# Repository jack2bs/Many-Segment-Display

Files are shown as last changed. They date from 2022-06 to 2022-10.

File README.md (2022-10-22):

# <center>Many Segment Display</center>
A four-digit display, made from 68 seven segment displays! By Jack Toubes. Inspired by [This Hackaday Project](https://hackaday.io/project/169632-7-segment-display-array-clock).

## Overview and conclusions
When I saw the above linked Hackaday project a while back, I thought it was the funniest thing I'd ever seen. But I didn't have the skills or money required to build something like it. Last year, however, when I got to my dorm room and realized that I hadn't brought a clock with me to school, I remembered that Hackaday project and I thought I'd give it a shot. I saw some places where I could improve the original, especially in the cost of the project. In the end the project took me a couple of months of on and off work (dictated by how busy I was with school). This project, like many of my other similar projects, offered me the opportunity to hone my electronic design skills, my ability to learn from datasheets, my ability to program in c and c++, and my ability to work with microcontrollers.

## Improvements from original project

For starters, I didn't copy a single line of code nor a component nor part of the schematic/board design from the original project. I was inspired by the idea, but not by the implementation.

In the original project on *Hackaday*, the LEDs are driven using dedicated LED driver ICs named MAX7219's, each of which could drive 8 seven segment displays. While this option certainly simplifies the board design and project in general, I decided to use 8-bit latches and some address decoders instead. 8 of these 8-bit latches are significantly cheaper than a single LED controller used in the *Hackaday* project, yet can control the same number of LEDs. This solution does require a significant number more pins/data lines, and a much more complicated circuit board, however I consider this worthwhile, considering that my LED driving solution costs $20-$25, whereas 9 of the dedicated LED drivers would cost between $90-$110 dollars. Using shift registers but not dedicated LED drivers would lead to a cost somewhere in between the two options, and could serve as a good compromise, considering that the board design would still be complex, but the number of data lines would be significantly reduced. One issue with the shift registers (and as a consequence also of the LED driver ICs), is that to change a single LED's state, you must update all of them. With my solution, you can change any LED at any time without affecting the others. The actual benefits to this are somewhat limited but could prove consequential in certain applications. One disadvantage with using latches is that they aren't designed to provide high amounts of current, and so (slightly more expensive) low current LEDs had to be chosen. This did however lead to a much less power hungry design than in the *Hackaday* project so perhaps this could also be considered a positive depending on your perspective

The original project used an Arduino. I used an STMG441 MCU on a custom controller board, because I have issues with Arduino as a platform (in my opinion, it's good for learning, but bad for everything else. Like how is acceptable for a pin change to take 80 cycles instead of 2 using memory-mapped io?!?! https://timodenk.com/blog/port-manipulation-and-arduino-digitalwrite-performance/).

I decreased the size of the clock significantly to lower costs, decrease power consumption, and because a smaller version fits better in my dorm. Even had I not done this, the price would have been somewhere around 1/3 - 1/2 that of the original, but by decreasing the size it was decreased even more.

The rest of my decisions were uninfluenced by the project (which is to say that as far as I'm aware my implementation is different from the original in every way except that both receive power over USB).

## Parts (prices as of part purchasing)

| Part | Part Number | Manufacturer | Price (Digikey) |  link | Price (Mouser) | link | Quantity |
|--|--|--|--|--|--|--|--|
|Display Parts
| 7-Seg Display | TDSR1360-IK | Vishay Semi | $1.43 for 10 | [Digikey](https://www.digikey.com/en/products/detail/vishay-semiconductor-opto-division/TDSR1360-IK/4074625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)| $1.29 for 10 | [Mouser](https://www.mouser.com/ProductDetail/Vishay-Semiconductors/TDSR1360-IK?qs=5csRq1wdUj5b9hoSL0MeOw%3D%3D) | 68+
| 8-bit Latch | 74LCX573FTAJ | Toshiba Semi | $0.207 for 100 | [Digikey](https://www.digikey.com/en/products/detail/toshiba-semiconductor-and-storage/74LCX573FT-AJ/7394038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)| $0.209 for 100 | [Mouser](https://www.mouser.com/ProductDetail/Toshiba/74LCX573FTAJ?qs=HXFqYaX1Q2ziMe06wbpr9A%3D%3D) | 68+
| 4:16 Decoder | 74HC4514D,653 | Nexperia Semi | $1.58 for 1 | [Digikey](https://www.digikey.com/en/products/detail/nexperia-usa-inc/74HC4514D-653/1230450)| $1.58 for 1 | [Mouser](https://www.mouser.com/ProductDetail/Nexperia/74HC4514D653?qs=P62ublwmbi%252Bpl7vJN0RpAQ%3D%3D) | 5+
| 3:8 (inv) Decoder | 74HC138D | Toshiba Semi | $0.41 for 1 | [Digikey](https://www.digikey.com/en/products/detail/toshiba-semiconductor-and-storage/74HC138D/5879983)| $0.41 for 1 | [Mouser](https://www.mouser.com/ProductDetail/Toshiba/74HC138DBJ?qs=sGAEpiMZZMsyYdr3R27aVzR9lUdn91FlizOQe6UfcVY%3D) | 1+
| Micro USB Conn | USB3076-30-A | GCT | $0.73 for 1 | [Digikey](https://www.digikey.com/en/products/detail/gct/USB3076-30-A/9859635)| $0.70 for 1 | [Mouser](https://www.mouser.com/ProductDetail/GCT/USB3076-30-A?qs=sGAEpiMZZMv0NwlthflBi%2FFq8vjDHSW5SIbIh%2F36DKc%3D) | 1+
| 1V8 LVR | AP2112K1.8TRG1 | Diodes Inc. | $0.37 for 1 | [Digikey](https://www.digikey.com/en/products/detail/diodes-incorporated/AP2112K-1-8TRG1/4470745)| $0.37 for 1 | [Mouser](https://www.mouser.com/ProductDetail/Diodes-Incorporated/AP2112K-18TRG1?qs=x6A8l6qLYDBx1xhw8AX2cw%3D%3D) | 4+
| 3V3 LVR | AP2139AK3.3TRG1 | Diodes Inc. | $0.42 for 1 | [Digikey](https://www.digikey.com/en/products/detail/diodes-incorporated/AP2139AK-3-3TRG1/4470806)| $0.42 for 1 | [Mouser](https://www.mouser.com/ProductDetail/Diodes-Incorporated/AP2139AK-33TRG1?qs=x6A8l6qLYDAPOgDKaB%252BUdg%3D%3D) | 1+
| 1uF Cap | C0805C105Z4VACTU | KEMET | $0.077 for 10 | [Digikey](https://www.digikey.com/en/products/detail/kemet/C0805C105Z4VAC7800/2211782)| $0.046 for 10 | [Mouser](https://www.mouser.com/ProductDetail/KEMET/C0805C105Z4VACTU?qs=XSafd0xJmRINotKjOdb5hw%3D%3D) | 10+
| |
| Controller Parts |
|Microcontroller | STM32G441 | STM | Not in stock | [Digikey](https://www.digikey.com/en/products/detail/stmicroelectronics/STM32G441CBT6/10326710) | Not in stock | [Mouser](https://www.mouser.com/ProductDetail/STMicroelectronics/STM32G441CBY6TR?qs=BJlw7L4Cy798X5l%252BURHnLA%3D%3D) | 1+
|32Khz Crystal | ECS-.327-12.5-34B-C-TR | ECS inc. | $0.80 for 1 | [Digikey](https://www.digikey.com/en/products/detail/ecs-inc/ECS-327-12-5-34B-C-TR/3927328) | $0.80 for 1 | [Mouser](https://www.mouser.com/ProductDetail/ECS/ECS-.327-12.5-34B-C-TR?qs=wo4x%252BUeoG8VWo%2FRy18ZjoQ%3D%3D) | 1+
|Assorted Components | N/A | N/A | ~$12 | | ~$12 | |

## Preliminary Considerations

Early on in the project, I wanted to test the electronics to confirm that my part selections would be satisfactory for the project. Specifically, I wanted to make sure the latches I would using could take 1.8v in VCC (and thus output 1.8v), but use 3.3v on their inputs. To do this, I designed a small breakout board for the latch, so that I could test it on a bread board, and ordered it from OSH Park for a couple of bucks. The KiCad project (including schematic, board layout, and Gerber files) is inside of the PCB_and_schematic/SubProjects/LatchTest directory.

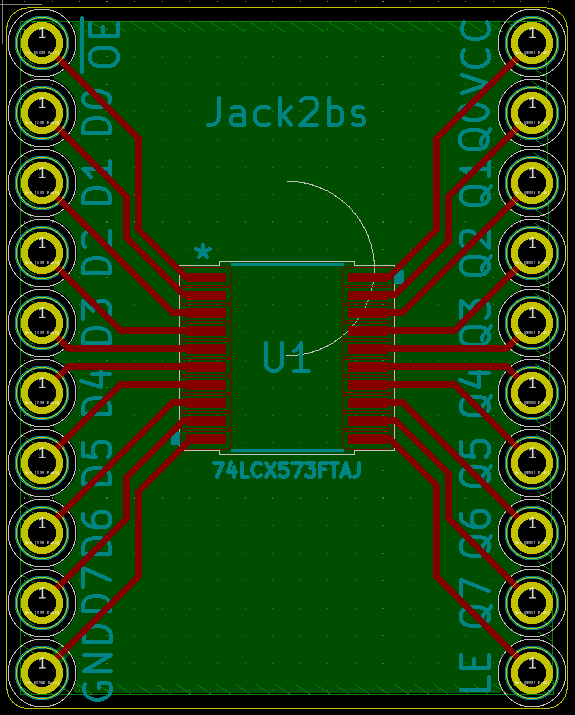
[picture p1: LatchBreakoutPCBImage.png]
Latch Breakout PCB


I also wanted to construct a development board for the STM32G441, which I decided I would use for controlling the display since I had some of them in my supplies and all microcontrollers were and still are out of stock. I designed and ordered a board from Osh Park (still small enough that the shipping for the two boards was more than the cost of the boards). I used the development board for testing RTC functionality and making sure that I could interconnect with the latches using basic GPIO. I have continued to use the development board for other prototyping and educational uses. The KiCad project files are inside of the same subprojects folder, but in the STM32G441DevBoard subdirectory.

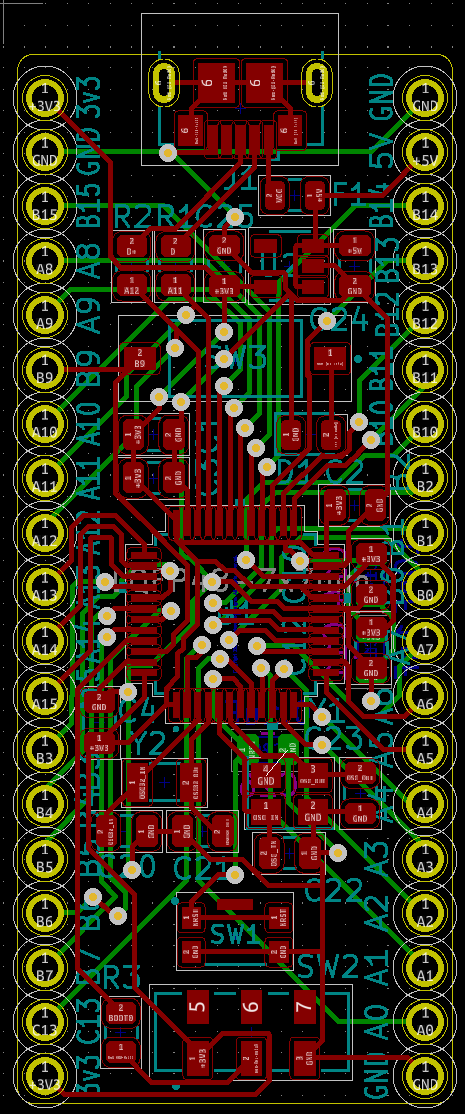
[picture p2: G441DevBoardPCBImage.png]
G441 Development board


## Laying out the board
After confirming that the electronics would work in the way I intended them to, I began laying out the board. I originally planned to build the controller directly into the board, but decided against this once I realized how many points of failure I was putting on one circuit board. Had I been producing this board with high tech, industrial grade soldering ovens I wouldn't have been concerned, but I was hand soldering the components, and with 68 20-TSSOP latches, and tons of other components (mostly surface mount), there was a lot that could go wrong. This meant laying out two separate boards.

First was the display itself. This took by far the greatest amount of time of any circuit board I've ever designed, and for good reason. With the final board having over 7500 Track segments spanning 660 nets, this boards complexity was greater than anything I'd ever attempted, and I was going to do it on a two layer board, which was covered both front and back with components. I started by drawing tracks somewhat randomly as I thought made sense, but I quickly realized this technique would not be effective. I deleted my progress and started again. This time, I took a more systematic approach. I created what to me seemed like "highways" of tracks which would carry the signals which needed to span the entire width of the board. This set up a good basis for using the top layer for signal transmission along the x axis, and the bottom layer for transmission along the y axis. After this, I moved again to fill in the connections that were not along the so called highways, but found myself running into trouble with the lack of space due to the components. The solution was to add complexity to the connections between the latches and the seven segment displays. Originally I had wanted to connect Q0 on the latch to A on the 7-segment display, Q1 to B, etc. I realized that for layout purposes this was not ideal, and so I redid all of the latch connections on the schematic, and again turned to the circuit board. Add another week or so of time, another 3 or 4 (hundred) problems solved, and I had a finished the circuit board.

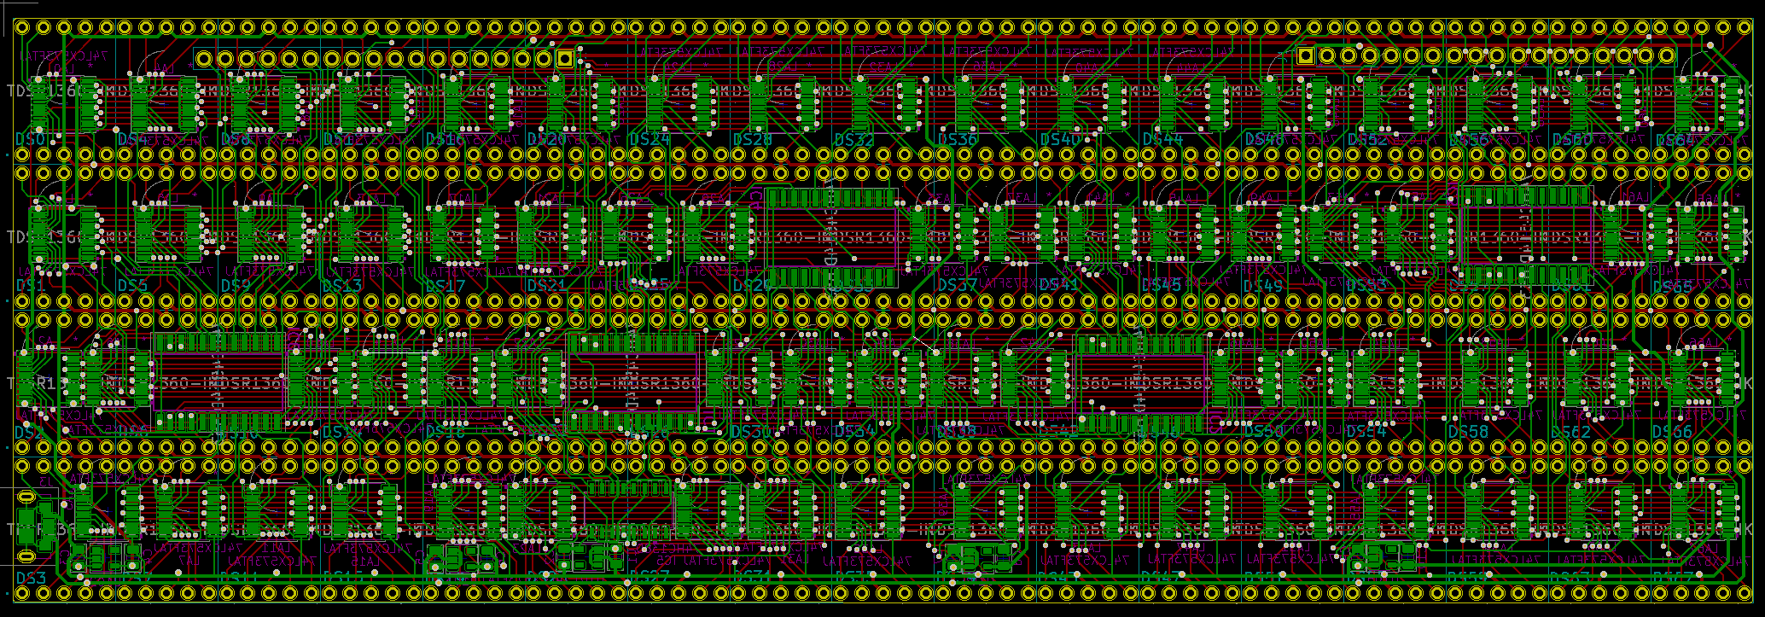
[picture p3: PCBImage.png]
Many Segment Display PCB


Laying out the controller was much easier, as I was able to base it heavily off of the development board I had designed earlier. Photos of the two circuit boards are located in this repository, and the KiCad project files are all in here as well (the controller is in the subprojects folder). The controller slots into the main board using header pins.

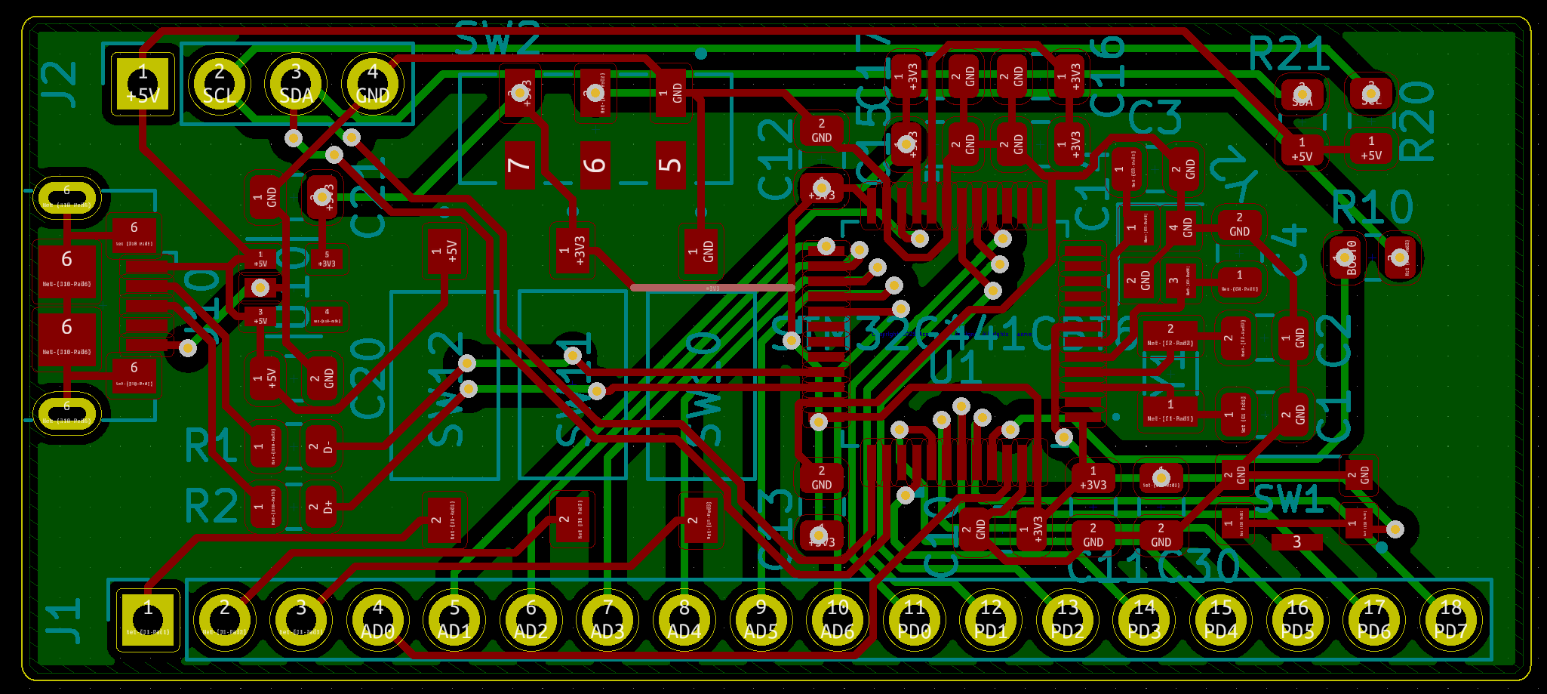
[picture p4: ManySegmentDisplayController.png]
Many Segment Display Controller


Once the boards came I spent a few days in one of the Makerspaces here at Princeton and I soldered on all of the components.

## Writing the software

It was relatively uncomplicated to write a short API for controlling the different cells of the display. The code for this is (admittedly) very messy and thrown together, but it wasn't the purpose of this project and it is functional. It isn't my best work by any stretch, and if I find the time between newer projects and my school work, I may update it.

Writing code to initialize and control the RTC (over USB using a CDC library) was similarly uncomplicated, but was made more difficult by the imperfections of my soldering job. Specifically, the quartz crystal wouldn't always begin oscillating. It took a significant amount of time, but eventually I realized that by cleaning up the solder job and removing the left over flux residue, I was able to coerce the crystal into oscillating.

I spent a few days after this calibrating the RTC until it was accurate to a fraction of a part per million, and then I put the final clock up in my dorm. 

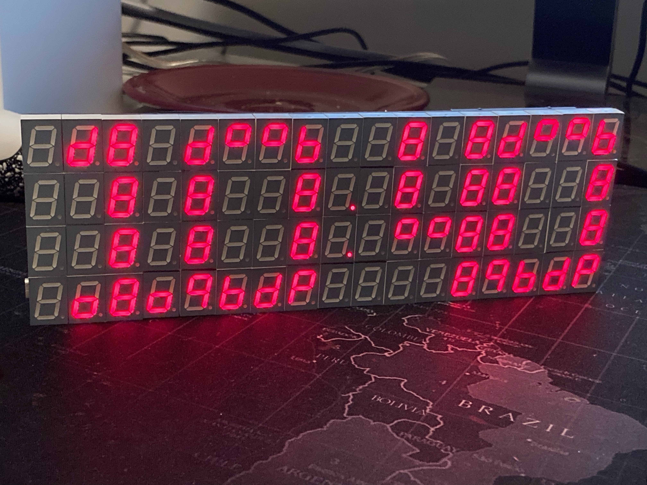
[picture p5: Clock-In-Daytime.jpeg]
Clock up and running


> Written with [StackEdit](https://stackedit.io/).

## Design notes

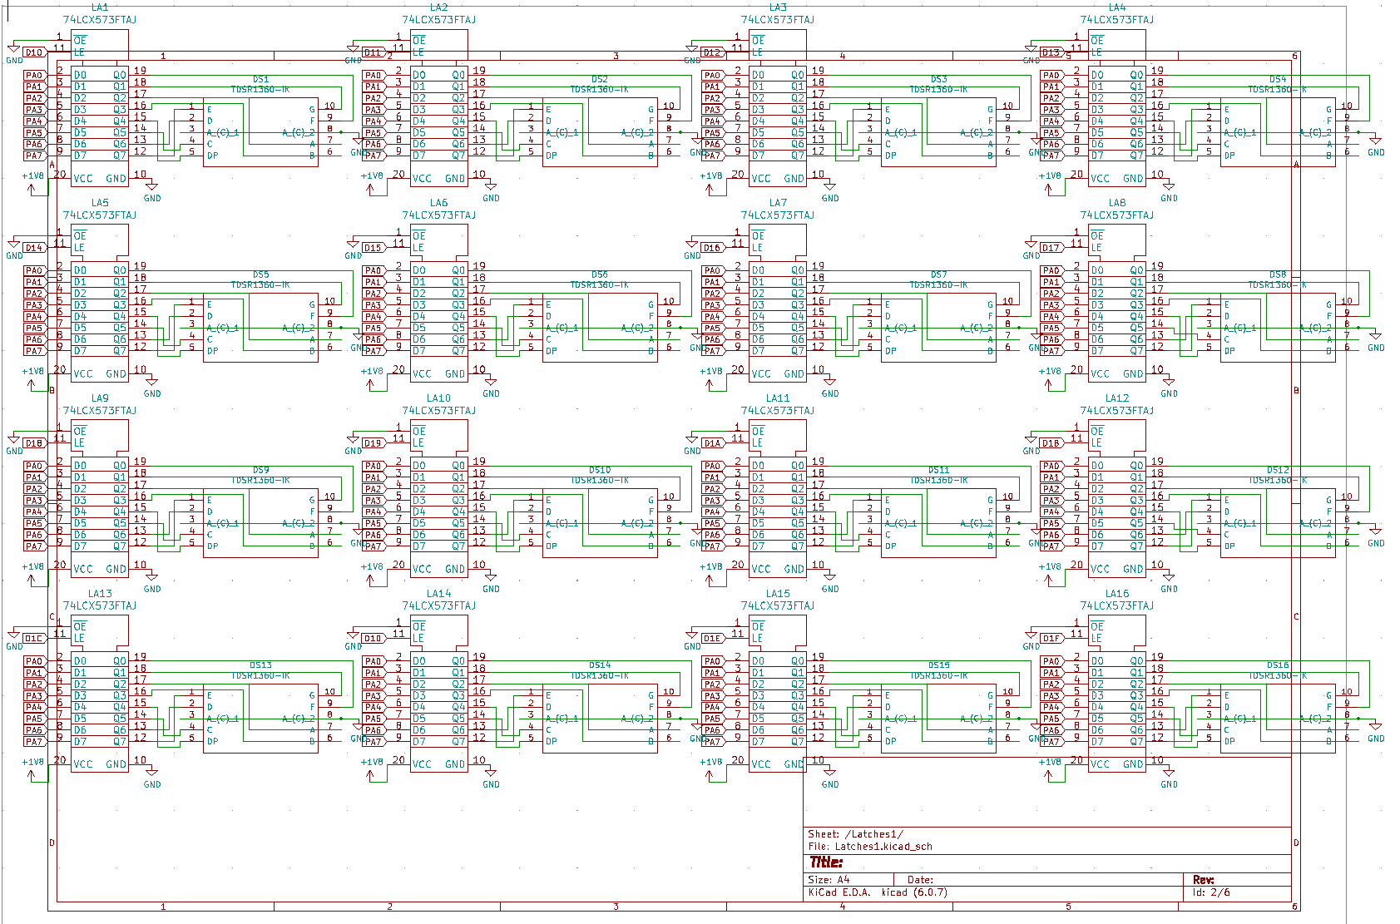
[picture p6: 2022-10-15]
SchematicLatchPage1.png

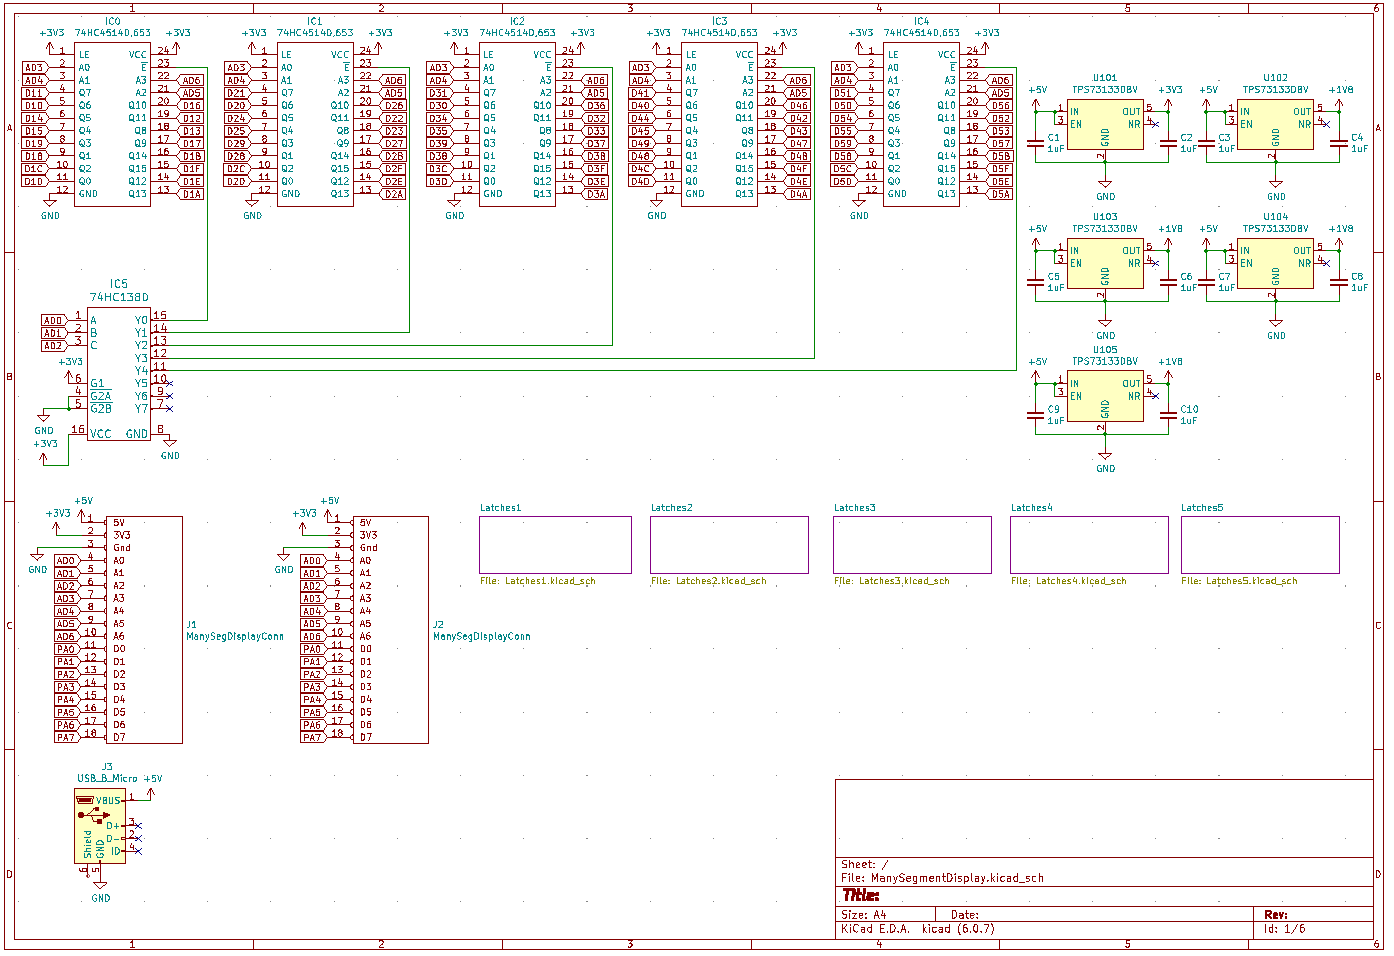
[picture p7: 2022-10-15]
MainSchematicImage.png

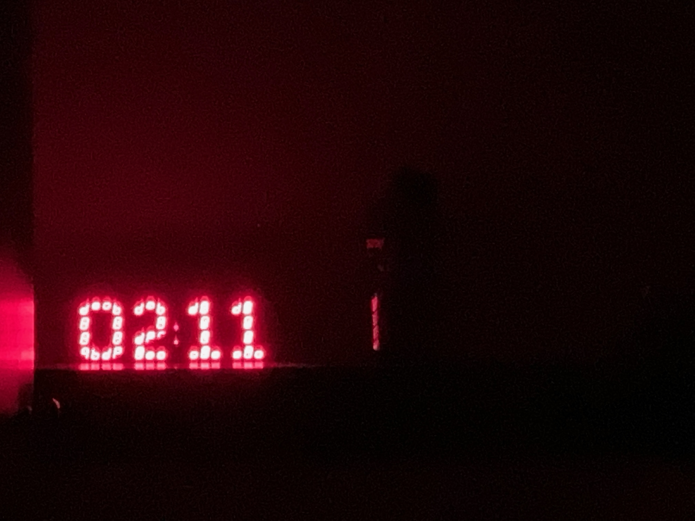
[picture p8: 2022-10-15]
Clock-In-Nighttime.jpeg

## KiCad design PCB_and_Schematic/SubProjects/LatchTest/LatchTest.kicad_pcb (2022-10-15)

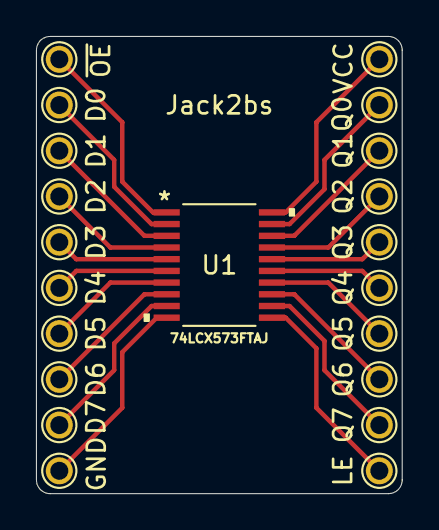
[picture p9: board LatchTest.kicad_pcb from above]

Board: 2 copper layers, 20.3 x 25.4 mm, 20 parts (0 on the bottom side), 19 nets.

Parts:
D0, D1, D2, D3, D4, D5, D6, D7: TestPoint; TestPoint_THTPad_D1.5mm_Drill0.7mm
GND: TestPoint; TestPoint_THTPad_D1.5mm_Drill0.7mm
LE: TestPoint; TestPoint_THTPad_D1.5mm_Drill0.7mm
Q0, Q1, Q2, Q3, Q4, Q5, Q6, Q7: TestPoint; TestPoint_THTPad_D1.5mm_Drill0.7mm
U1: 74LCX573FTAJ
VCC: TestPoint; TestPoint_THTPad_D1.5mm_Drill0.7mm

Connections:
unnamed: D0.1, U1.2
unnamed: D1.1, U1.3
unnamed: D2.1, U1.4
unnamed: D3.1, U1.5
unnamed: D4.1, U1.6
unnamed: D5.1, U1.7
unnamed: D6.1, U1.8
unnamed: D7.1, U1.9
unnamed: Q0.1, U1.19
unnamed: Q1.1, U1.18
unnamed: Q2.1, U1.17
unnamed: Q3.1, U1.16
unnamed: Q4.1, U1.15
unnamed: Q5.1, U1.14
unnamed: Q6.1, U1.13
unnamed: Q7.1, U1.12
unnamed: LE.1, U1.11
unnamed: GND.1, U1.10
unnamed: U1.20, VCC.1

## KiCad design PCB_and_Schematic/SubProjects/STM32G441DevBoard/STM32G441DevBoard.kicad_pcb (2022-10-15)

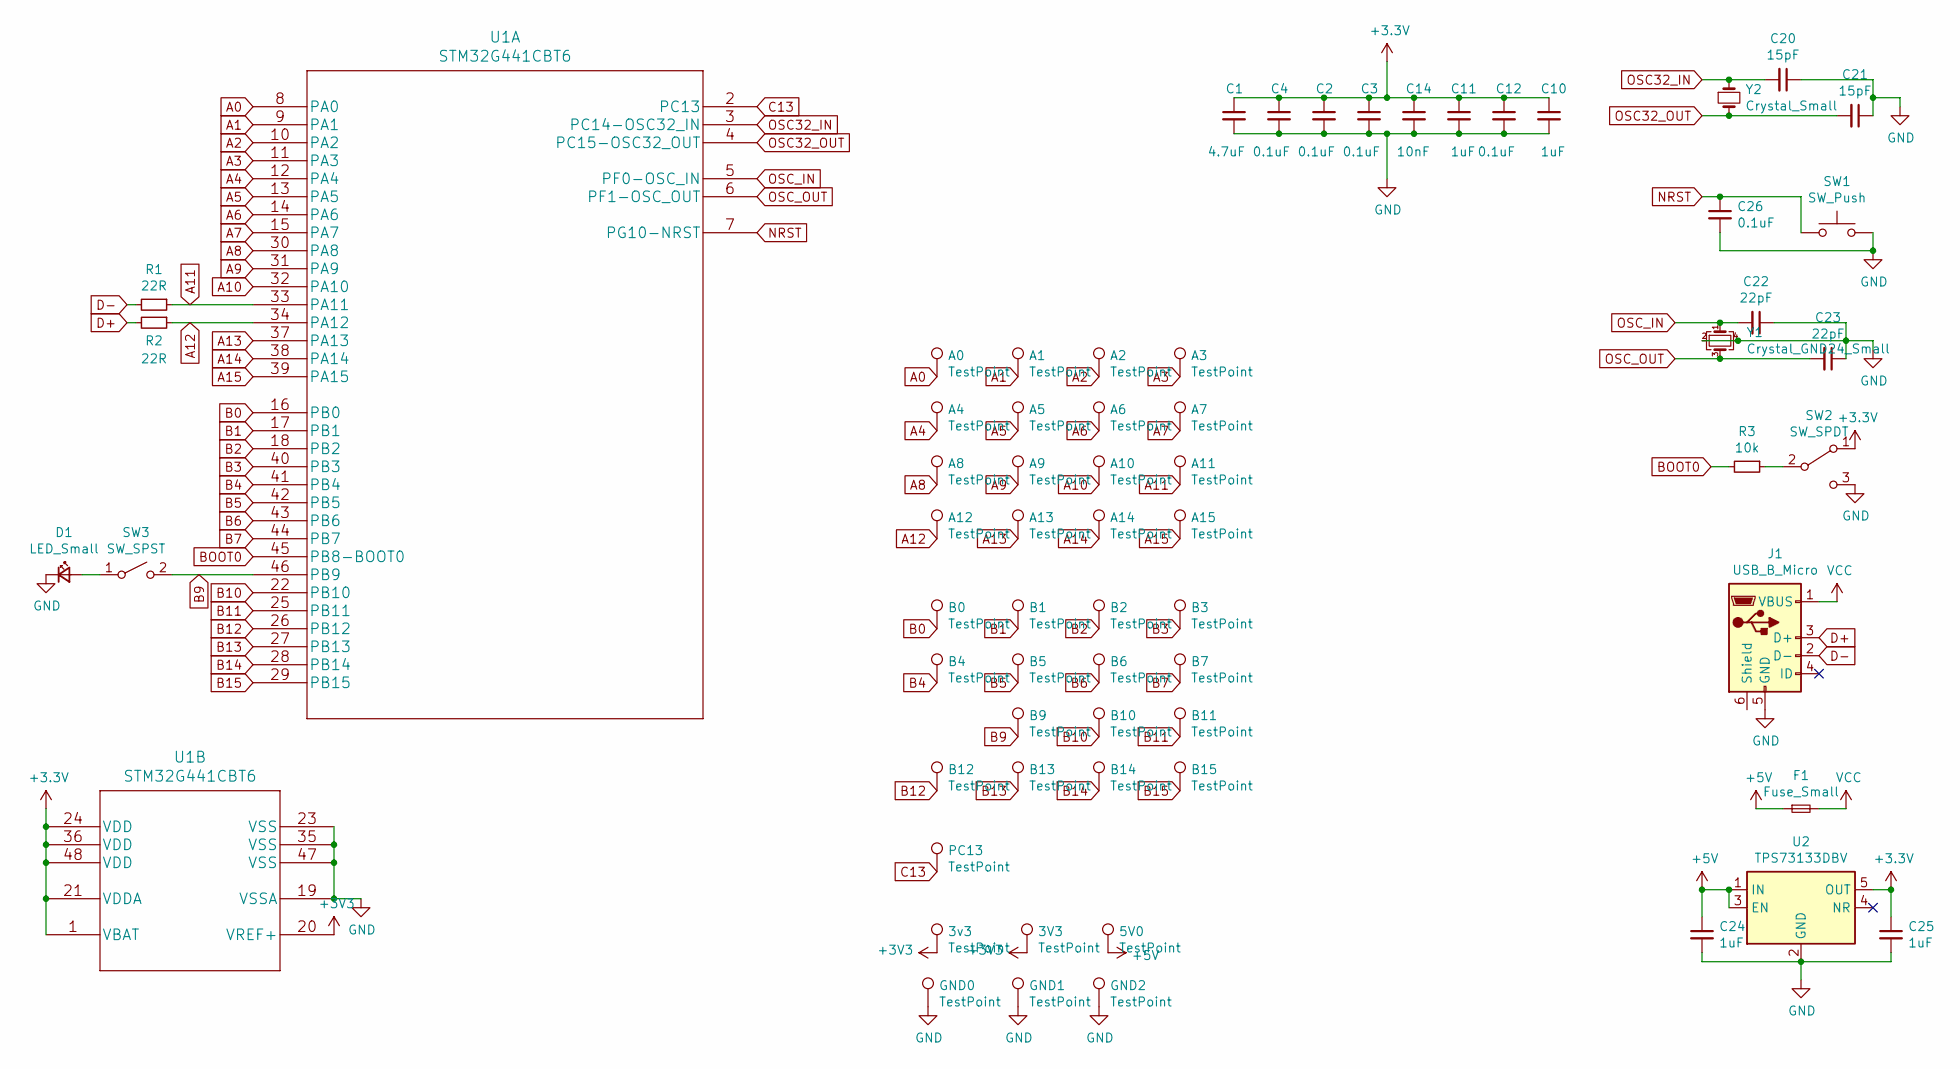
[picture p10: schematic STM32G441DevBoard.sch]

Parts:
3V3, 3v3, 5V0: TestPoint; TestPoint_THTPad_D1.775mm_Drill1.2mm
A0, A1, A2, A3, A4, A5, A6, A7, A8, A9, A10, A11, A12, A13, A14, A15: TestPoint; TestPoint_THTPad_D1.775mm_Drill1.2mm
B0, B1, B2, B3, B4, B5, B6, B7, B9, B10, B11, B12, B13, B14, B15: TestPoint; TestPoint_THTPad_D1.775mm_Drill1.2mm
C1: 4.7uF; C_0805_2012Metric
C2, C3, C4, C12, C26: 0.1uF; C_0805_2012Metric
C10, C11, C24, C25: 1uF; C_0805_2012Metric
C14: 10nF; C_0805_2012Metric
C20, C21: 15pF; C_0805_2012Metric
C22, C23: 22pF; C_0805_2012Metric
D1: LED_Small; LED_0805_2012Metric
F1: Fuse_Small; Fuse_0805_2012Metric
GND0, GND1, GND2: TestPoint; TestPoint_THTPad_D1.775mm_Drill1.2mm
J1: USB_B_Micro; USB_Micro-B_GCT_USB3076-30-A
PC13: TestPoint; TestPoint_THTPad_D1.775mm_Drill1.2mm
R1, R2: 22R; R_0805_2012Metric
R3: 10k; R_0805_2012Metric
SW1: SW_Push; SW_Push_KMR421GULCLFS
SW2: SW_SPDT; SW_SPDT_JS202011JCQN
SW3: SW_SPST; SW_DIP_SPSTx01_DS04-254-2-01BK-SMT
U1: STM32G441CBT6
U2: TPS73133DBV; SOT-23-5
Y1: Crystal_GND24_Small; Crystal_SMD_3225-4Pin_3.2x2.5mm
Y2: Crystal_Small; Crystal_SMD_3215-2Pin_3.2x1.5mm

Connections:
+5V: 5V0.1, C24.1, F1.1, U2.1 (IN), U2.3 (EN); also elsewhere on the board
A0: A0.1, U1.8 (PA0)
A1: A1.1, U1.9 (PA1)
A2: A2.1, U1.10 (PA2)
A3: A3.1, U1.11 (PA3)
A4: A4.1, U1.12 (PA4)
A5: A5.1, U1.13 (PA5)
A6: A6.1, U1.14 (PA6)
A7: A7.1, U1.15 (PA7)
A8: A8.1, U1.30 (PA8)
A9: A9.1, U1.31 (PA9)
A10: A10.1, U1.32 (PA10)
A11: A11.1, R1.1, U1.33 (PA11)
A12: A12.1, R2.1, U1.34 (PA12)
A13: A13.1, U1.37 (PA13)
A14: A14.1, U1.38 (PA14)
A15: A15.1, U1.39 (PA15)
B0: B0.1, U1.16 (PB0)
B1: B1.1, U1.17 (PB1)
B2: B2.1, U1.18 (PB2)
B3: B3.1, U1.40 (PB3)
B4: B4.1, U1.41 (PB4)
B5: B5.1, U1.42 (PB5)
B6: B6.1, U1.43 (PB6)
B7: B7.1, U1.44 (PB7)
B9: B9.1, SW3.2 (B), U1.46 (PB9)
B10: B10.1, U1.22 (PB10)
B11: B11.1, U1.25 (PB11)
B12: B12.1, U1.26 (PB12)
B13: B13.1, U1.27 (PB13)
B14: B14.1, U1.28 (PB14)
B15: B15.1, U1.29 (PB15)
BOOT0: R3.2, U1.45 (PB8-BOOT0)
C13: PC13.1, U1.2 (PC13); also elsewhere on the board
D+: J1.3 (D+), R2.2
D-: J1.2 (D-), R1.2
GND: C1.2, C2.2, C3.2, C4.2, C10.2, C11.2, C12.2, C14.2, C20.1, C21.1, C22.1, C23.1, C24.2, C25.2, C26.2, D1.1 (K), GND0.1, GND1.1, GND2.1, J1.5 (GND), SW1.2, SW2.3 (C), U1.19 (VSSA), U1.23 (VSS), U1.35 (VSS), U1.47 (VSS), U2.2 (GND), Y1.2, Y1.4; also elsewhere on the board
NRST: C26.1, SW1.1, U1.7 (PG10-NRST)
unnamed: D1.2 (A), SW3.1 (A)
unnamed: R3.1, SW2.2 (B)
OSC32_IN: C20.2, U1.3 (PC14-OSC32_IN), Y2.1
OSC32_OUT: C21.2, U1.4 (PC15-OSC32_OUT), Y2.2
OSC_IN: C22.2, U1.5 (PF0-OSC_IN), Y1.1
OSC_OUT: C23.2, U1.6 (PF1-OSC_OUT), Y1.3
VCC: F1.2, J1.1 (VBUS)

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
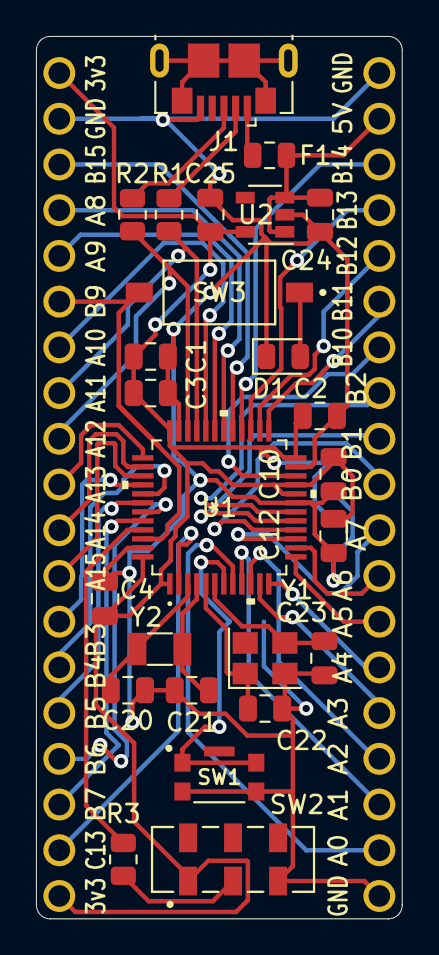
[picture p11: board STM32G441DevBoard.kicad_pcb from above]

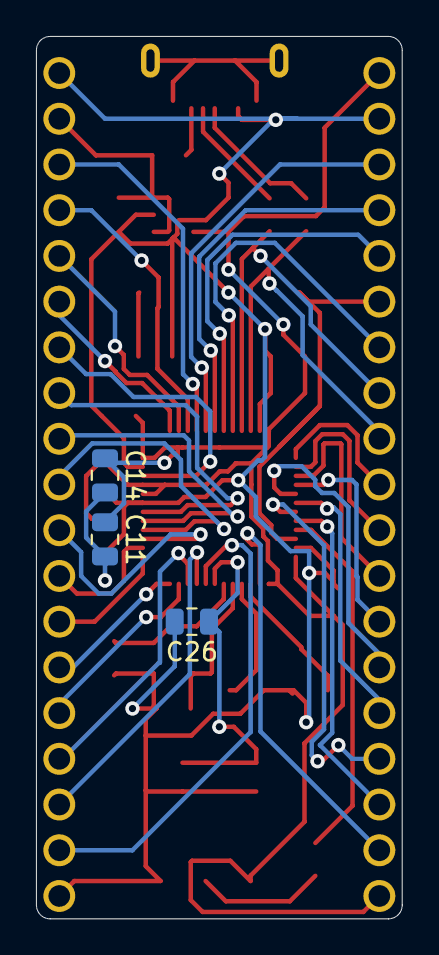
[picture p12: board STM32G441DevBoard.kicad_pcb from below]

Board: 2 copper layers, 20.3 x 49.0 mm, 66 parts (3 on the bottom side), 46 nets.

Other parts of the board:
3v3#2, 5V: TestPoint; TestPoint_THTPad_D1.775mm_Drill1.2mm
C13: TestPoint; TestPoint_THTPad_D1.775mm_Drill1.2mm
GND: TestPoint; TestPoint_THTPad_D1.775mm_Drill1.2mm
GND#2, GND#3: TestPoint; TestPoint_THTPad_D1.775mm_Drill1.2mm

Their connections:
+5V: 5V.1; also elsewhere on the board
C13: C13.1; also elsewhere on the board
GND: GND.1, GND#2.1, GND#3.1; also elsewhere on the board

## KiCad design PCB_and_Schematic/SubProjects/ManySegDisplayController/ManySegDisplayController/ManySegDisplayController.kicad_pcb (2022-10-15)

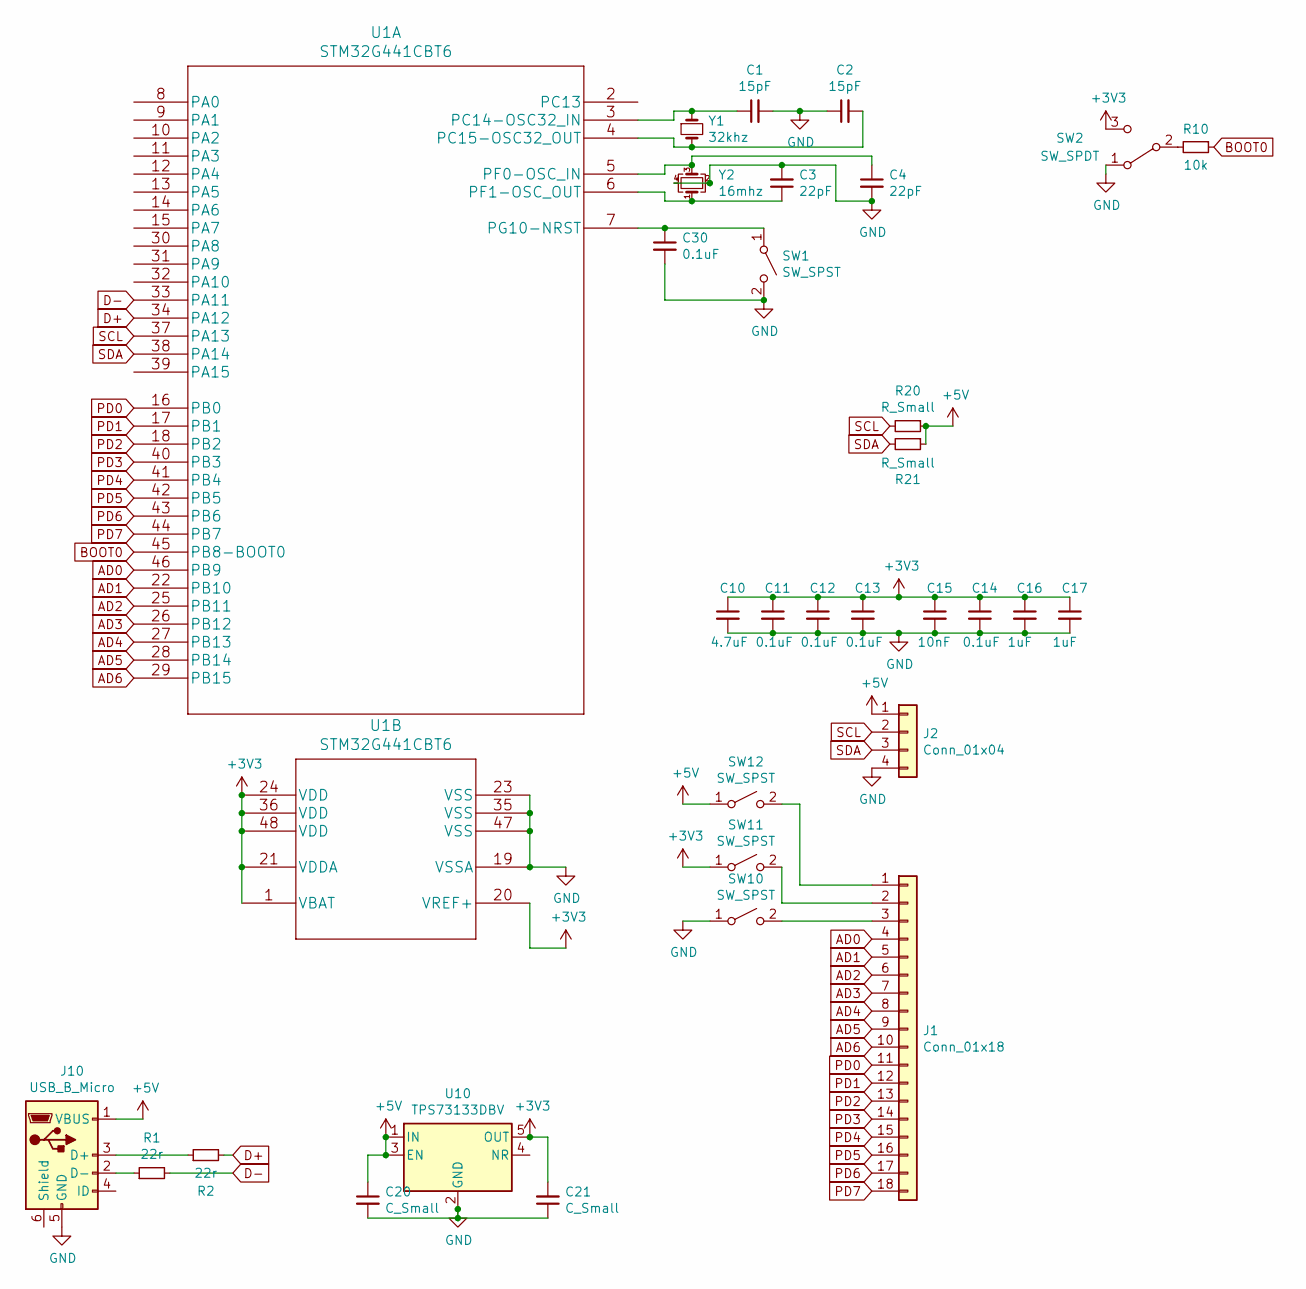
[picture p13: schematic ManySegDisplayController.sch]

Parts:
C1, C2: 15pF; C_0805_2012Metric
C3, C4: 22pF; C_0805_2012Metric
C10: 4.7uF; C_0805_2012Metric
C11, C12, C13, C14, C30: 0.1uF; C_0805_2012Metric
C15: 10nF; C_0805_2012Metric
C16, C17: 1uF; C_0805_2012Metric
C20, C21: C_Small; C_0805_2012Metric
J1: Conn_01x18; PinSocket_1x18_P2.54mm_Vertical
J2: Conn_01x04; PinSocket_1x04_P2.54mm_Vertical
J10: USB_B_Micro; USB_Micro-B_GCT_USB3076-30-A
R1, R2: 22r; R_0805_2012Metric
R10: 10k; R_0805_2012Metric
R20, R21: R_Small; R_0805_2012Metric
SW1: SW_SPST; SW_Push_KMR421GULCLFS
SW2: SW_SPDT; SW_SPDT_JS202011JCQN
SW10, SW11, SW12: SW_SPST; SW_DIP_SPSTx01_DS04-254-2-01BK-SMT
U1: STM32G441CBT6
U10: TPS73133DBV; SOT-23-5
Y1: 32khz; Crystal_SMD_3215-2Pin_3.2x1.5mm
Y2: 16mhz; Crystal_SMD_2520-4Pin_2.5x2.0mm

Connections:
+3V3: C10.1, C11.1, C12.1, C13.1, C14.1, C15.1, C16.1, C17.1, C21.2, SW2.3 (C), SW11.1 (A), U1.1 (VBAT), U1.20 (VREF+), U1.21 (VDDA), U1.24 (VDD), U1.36 (VDD), U1.48 (VDD), U10.5 (OUT)
+5V: C20.1, J2.1, J10.1 (VBUS), R20.1, R21.1, SW12.1 (A), U10.1 (IN), U10.3 (EN)
AD0: J1.4, U1.46 (PB9)
AD1: J1.5, U1.22 (PB10)
AD2: J1.6, U1.25 (PB11)
AD3: J1.7, U1.26 (PB12)
AD4: J1.8, U1.27 (PB13)
AD5: J1.9, U1.28 (PB14)
AD6: J1.10, U1.29 (PB15)
BOOT0: R10.1, U1.45 (PB8-BOOT0)
D+: R2.2, U1.34 (PA12)
D-: R1.2, U1.33 (PA11)
GND: C1.2, C2.1, C3.2, C4.2, C10.2, C11.2, C12.2, C13.2, C14.2, C15.2, C16.2, C17.2, C20.2, C21.1, C30.2, J2.4, J10.5 (GND), SW1.2 (B), SW2.1 (A), SW10.1 (A), U1.19 (VSSA), U1.23 (VSS), U1.35 (VSS), U1.47 (VSS), U10.2 (GND), Y2.2, Y2.4
unnamed: C1.1, U1.3 (PC14-OSC32_IN), Y1.1
unnamed: C2.2, U1.4 (PC15-OSC32_OUT), Y1.2
unnamed: C3.1, U1.6 (PF1-OSC_OUT), Y2.1
unnamed: C4.1, U1.5 (PF0-OSC_IN), Y2.3
unnamed: C30.1, SW1.1 (A), U1.7 (PG10-NRST)
unnamed: J1.1, SW12.2 (B)
unnamed: J1.2, SW11.2 (B)
unnamed: J1.3, SW10.2 (B)
unnamed: J10.2 (D-), R1.1
unnamed: J10.3 (D+), R2.1
unnamed: R10.2, SW2.2 (B)
PD0: J1.11, U1.16 (PB0)
PD1: J1.12, U1.17 (PB1)
PD2: J1.13, U1.18 (PB2)
PD3: J1.14, U1.40 (PB3)
PD4: J1.15, U1.41 (PB4)
PD5: J1.16, U1.42 (PB5)
PD6: J1.17, U1.43 (PB6)
PD7: J1.18, U1.44 (PB7)
SCL: J2.2, R20.2, U1.37 (PA13)
SDA: J2.3, R21.2, U1.38 (PA14)

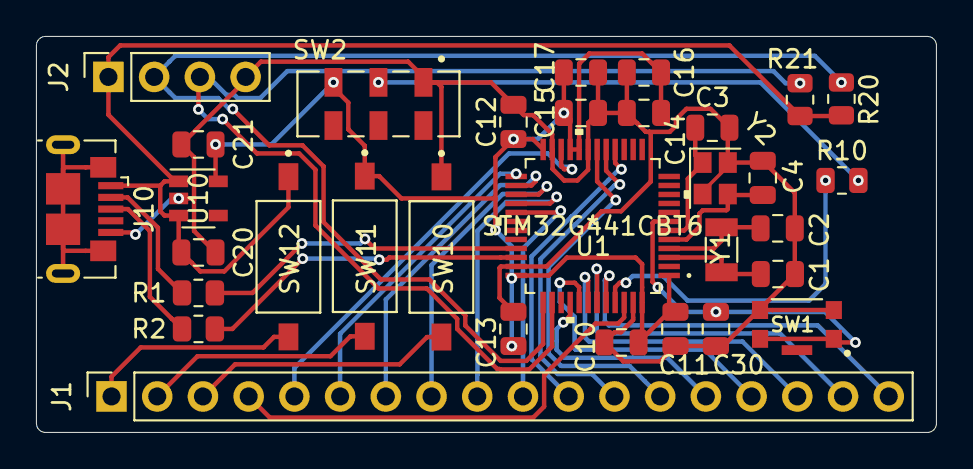
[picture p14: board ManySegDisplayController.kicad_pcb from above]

Board: 2 copper layers, 50.0 x 22.0 mm, 32 parts (0 on the bottom side), 34 nets.

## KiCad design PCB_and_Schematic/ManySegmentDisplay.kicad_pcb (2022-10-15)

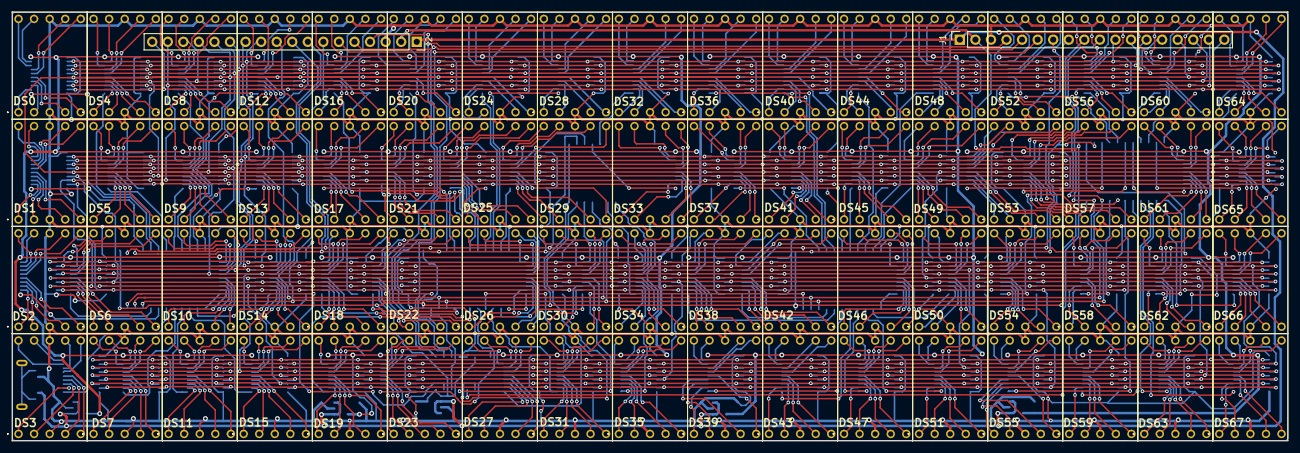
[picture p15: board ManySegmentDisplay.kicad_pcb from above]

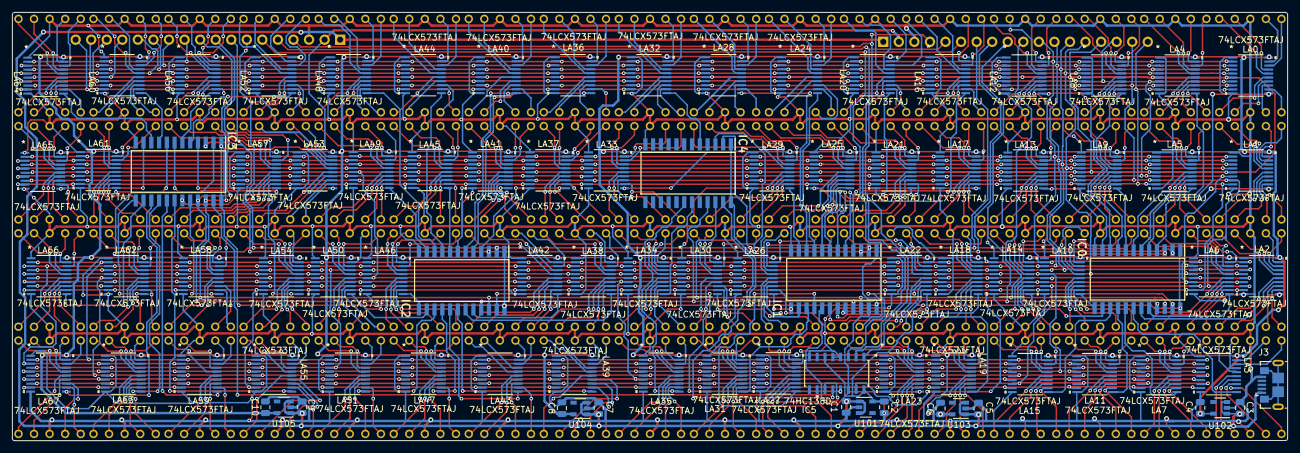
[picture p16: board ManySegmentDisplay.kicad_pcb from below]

Board: 2 copper layers, 208.1 x 69.9 mm, 160 parts (90 on the bottom side), 636 nets.

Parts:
C1, C2, C3, C4, C5, C6, C7, C8, C9, C10: 1uF; C_0805_2012Metric
DS0, DS1, DS2, DS3, DS4, DS5, DS6, DS7, DS8, DS9, DS10, DS11, DS12, DS13, DS14, DS15, DS16, DS17, DS18, DS19, DS20, DS21, DS22, DS23, DS24, DS25, DS26, DS27, DS28, DS29, DS30, DS31, DS32, DS33, DS34, DS35, DS36, DS37, DS38, DS39, DS40, DS41, DS42, DS43, DS44, DS45, DS46, DS47, DS48, DS49, DS50, DS51, DS52, DS53, DS54, DS55, DS56, DS57, DS58, DS59, DS60, DS61, DS62, DS63, DS64, DS65, DS66, DS67: TDSR1360-IK; TDSR1360IK
IC0, IC1, IC2, IC3, IC4: 74HC4514D,653; SOIC127P1032X265-24N
IC5: 74HC138D
J1, J2: ManySegDisplayConn; PinSocket_1x18_P2.54mm_Vertical
J3: USB_B_Micro; USB_Micro-B_GCT_USB3076-30-A
LA0, LA1, LA2, LA3, LA4, LA5, LA6, LA7, LA8, LA9, LA10, LA11, LA12, LA13, LA14, LA15, LA16, LA17, LA18, LA19, LA20, LA21, LA22, LA23, LA24, LA25, LA26, LA27, LA28, LA29, LA30, LA31, LA32, LA33, LA34, LA35, LA36, LA37, LA38, LA39, LA40, LA41, LA42, LA43, LA44, LA45, LA46, LA47, LA48, LA49, LA50, LA51, LA52, LA53, LA54, LA55, LA56, LA57, LA58, LA59, LA60, LA61, LA62, LA63, LA64, LA65, LA66, LA67: 74LCX573FTAJ
U101, U102, U103, U104, U105: TPS73133DBV; SOT-23-5

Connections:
+1V8: C4.1, C6.1, C8.1, C10.1, LA0.20, LA1.20, LA2.20, LA3.20, LA4.20, LA5.20, LA6.20, LA7.20, LA8.20, LA9.20, LA10.20, LA11.20, LA12.20, LA13.20, LA14.20, LA15.20, LA16.20, LA17.20, LA18.20, LA19.20, LA20.20, LA21.20, LA22.20, LA23.20, LA24.20, LA25.20, LA26.20, LA27.20, LA28.20, LA29.20, LA30.20, LA31.20, LA32.20, LA33.20, LA34.20, LA35.20, LA36.20, LA37.20, LA38.20, LA39.20, LA40.20, LA41.20, LA42.20, LA43.20, LA44.20, LA45.20, LA46.20, LA47.20, LA48.20, LA49.20, LA50.20, LA51.20, LA52.20, LA53.20, LA54.20, LA55.20, LA56.20, LA57.20, LA58.20, LA59.20, LA60.20, LA61.20, LA62.20, LA63.20, LA64.20, LA65.20, LA66.20, LA67.20, U102.5, U103.5, U104.5, U105.5
+3V3: C2.1, IC0.1, IC0.24, IC1.1, IC1.24, IC2.1, IC2.24, IC3.1, IC3.24, IC4.1, IC4.24, IC5.6, IC5.16, J1.2, J2.2, U101.5
+5V: C1.1, C3.1, C5.1, C7.1, C9.1, J1.1, J2.1, J3.1, U101.1, U101.3, U102.1, U102.3, U103.1, U103.3, U104.1, U104.3, U105.1, U105.3
AD0: IC5.1, J1.4, J2.4
AD1: IC5.2, J1.5, J2.5
AD2: IC5.3, J1.6, J2.6
AD3: IC0.2, IC1.2, IC2.2, IC3.2, IC4.2, J1.7, J2.7
AD4: IC0.3, IC1.3, IC2.3, IC3.3, IC4.3, J1.8, J2.8
AD5: IC0.21, IC1.21, IC2.21, IC3.21, IC4.21, J1.9, J2.9
AD6: IC0.22, IC1.22, IC2.22, IC3.22, IC4.22, J1.10, J2.10
D1A: IC0.13, LA10.11
D1B: IC0.16, LA11.11
D1C: IC0.10, LA12.11
D1D: IC0.11, LA13.11
D1E: IC0.14, LA14.11
D1F: IC0.15, LA15.11
D2A: IC1.13, LA26.11
D2B: IC1.16, LA27.11
D2C: IC1.10, LA28.11
D2D: IC1.11, LA29.11
D2E: IC1.14, LA30.11
D2F: IC1.15, LA31.11
D3A: IC2.13, LA46.11
D3B: IC2.16, LA47.11
D3C: IC2.10, LA48.11
D3D: IC2.11, LA49.11
D3E: IC2.14, LA50.11
D3F: IC2.15, LA51.11
D4A: IC3.13, LA62.11
D4B: IC3.16, LA63.11
D4C: IC3.10, LA64.11
D4D: IC3.11, LA65.11
D4E: IC3.14, LA66.11
D4F: IC3.15, LA67.11
D10: IC0.5, LA0.11
D11: IC0.4, LA1.11
D12: IC0.19, LA2.11
D13: IC0.18, LA3.11
D14: IC0.6, LA4.11
D15: IC0.7, LA5.11
D16: IC0.20, LA6.11
D17: IC0.17, LA7.11
D18: IC0.9, LA8.11
D19: IC0.8, LA9.11
D20: IC1.5, LA16.11
D21: IC1.4, LA17.11
D22: IC1.19, LA18.11
D23: IC1.18, LA19.11
D24: IC1.6, LA20.11
D25: IC1.7, LA21.11
D26: IC1.20, LA22.11
D27: IC1.17, LA23.11
D28: IC1.9, LA24.11
D29: IC1.8, LA25.11
D30: IC2.5, LA36.11
D31: IC2.4, LA37.11
D32: IC2.19, LA38.11
D33: IC2.18, LA39.11
D34: IC2.6, LA40.11
D35: IC2.7, LA41.11
D36: IC2.20, LA42.11
D37: IC2.17, LA43.11
D38: IC2.9, LA44.11
D39: IC2.8, LA45.11
D40: IC3.5, LA52.11
D41: IC3.4, LA53.11
D42: IC3.19, LA54.11
D43: IC3.18, LA55.11
D44: IC3.6, LA56.11
D45: IC3.7, LA57.11
D46: IC3.20, LA58.11
D47: IC3.17, LA59.11
D48: IC3.9, LA60.11
D49: IC3.8, LA61.11
D50: IC4.5, LA32.11
D51: IC4.4, LA33.11
D52: IC4.19, LA34.11
D53: IC4.18, LA35.11
GND: C1.2, C2.2, C3.2, C4.2, C5.2, C6.2, C7.2, C8.2, C9.2, C10.2, DS0.3, DS0.8, DS1.3, DS1.8, DS2.3, DS2.8, DS3.3, DS3.8, DS4.3, DS4.8, DS5.3, DS5.8, DS6.3, DS6.8, DS7.3, DS7.8, DS8.3, DS8.8, DS9.3, DS9.8, DS10.3, DS10.8, DS11.3, DS11.8, DS12.3, DS12.8, DS13.3, DS13.8, DS14.3, DS14.8, DS15.3, DS15.8, DS16.3, DS16.8, DS17.3, DS17.8, DS18.3, DS18.8, DS19.3, DS19.8, DS20.3, DS20.8, DS21.3, DS21.8, DS22.3, DS22.8, DS23.3, DS23.8, DS24.3, DS24.8, DS25.3, DS25.8, DS26.3, DS26.8, DS27.3, DS27.8, DS28.3, DS28.8, DS29.3, DS29.8, DS30.3, DS30.8, DS31.3, DS31.8, DS32.3, DS32.8, DS33.3, DS33.8, DS34.3, DS34.8, DS35.3, DS35.8, DS36.3, DS36.8, DS37.3, DS37.8, DS38.3, DS38.8, DS39.3, DS39.8, DS40.3, DS40.8, DS41.3, DS41.8, DS42.3, DS42.8, DS43.3, DS43.8, DS44.3, DS44.8, DS45.3, DS45.8, DS46.3, DS46.8, DS47.3, DS47.8, DS48.3, DS48.8, DS49.3, DS49.8, DS50.3, DS50.8, DS51.3, DS51.8, DS52.3, DS52.8, DS53.3, DS53.8, DS54.3, DS54.8, DS55.3, DS55.8, DS56.3, DS56.8, DS57.3, DS57.8, DS58.3, DS58.8, DS59.3, DS59.8, DS60.3, DS60.8, DS61.3, DS61.8, DS62.3, DS62.8, DS63.3, DS63.8, DS64.3, DS64.8, DS65.3, DS65.8, DS66.3, DS66.8, DS67.3, DS67.8, IC0.12, IC1.12, IC2.12, IC3.12, IC4.12, IC5.4, IC5.5, IC5.8, J1.3, J2.3, J3.5, LA0.1, LA0.10, LA1.1, LA1.10, LA2.1, LA2.10, LA3.1, LA3.10, LA4.1, LA4.10, LA5.1, LA5.10, LA6.1, LA6.10, LA7.1, LA7.10, LA8.1, LA8.10, LA9.1, LA9.10, LA10.1, LA10.10, LA11.1, LA11.10, LA12.1, LA12.10, LA13.1, LA13.10, LA14.1, LA14.10, LA15.1, LA15.10, LA16.1, LA16.10, LA17.1, LA17.10, LA18.1, LA18.10, LA19.1, LA19.10, LA20.1, LA20.10, LA21.1, LA21.10, LA22.1, LA22.10, LA23.1, LA23.10, LA24.1, LA24.10, LA25.1, LA25.10, LA26.1, LA26.10, LA27.1, LA27.10, LA28.1, LA28.10, LA29.1, LA29.10, LA30.1, LA30.10, LA31.1, LA31.10, LA32.1, LA32.10, LA33.1, LA33.10, LA34.1, LA34.10, LA35.1, LA35.10, LA36.1, LA36.10, LA37.1, LA37.10, LA38.1, LA38.10, LA39.1, LA39.10, LA40.1, LA40.10, LA41.1, LA41.10, LA42.1, LA42.10, LA43.1, LA43.10, LA44.1, LA44.10, LA45.1, LA45.10, LA46.1, LA46.10, LA47.1, LA47.10, LA48.1, LA48.10, LA49.1, LA49.10, LA50.1, LA50.10, LA51.1, LA51.10, LA52.1, LA52.10, LA53.1, LA53.10, LA54.1, LA54.10, LA55.1, LA55.10, LA56.1, LA56.10, LA57.1, LA57.10, LA58.1, LA58.10, LA59.1, LA59.10, LA60.1, LA60.10, LA61.1, LA61.10, LA62.1, LA62.10, LA63.1, LA63.10, LA64.1, LA64.10, LA65.1, LA65.10, LA66.1, LA66.10, LA67.1, LA67.10, U101.2, U102.2, U103.2, U104.2, U105.2
unnamed: DS0.1, LA0.12
unnamed: DS0.2, LA0.13
unnamed: DS0.4, LA0.14
unnamed: DS0.5, LA0.15
unnamed: DS0.6, LA0.16
unnamed: DS0.7, LA0.17
unnamed: DS0.9, LA0.19
unnamed: DS0.10, LA0.18
unnamed: DS1.1, LA1.12
unnamed: DS1.2, LA1.13
unnamed: DS1.4, LA1.14
unnamed: DS1.5, LA1.15
unnamed: DS1.6, LA1.16
unnamed: DS1.7, LA1.17
unnamed: DS1.9, LA1.19
unnamed: DS1.10, LA1.18
unnamed: DS2.1, LA2.12
unnamed: DS2.2, LA2.13
unnamed: DS2.4, LA2.14
unnamed: DS2.5, LA2.15
unnamed: DS2.6, LA2.16
unnamed: DS2.7, LA2.17
unnamed: DS2.9, LA2.19
unnamed: DS2.10, LA2.18
unnamed: DS3.1, LA3.12
unnamed: DS3.2, LA3.13
unnamed: DS3.4, LA3.14
unnamed: DS3.5, LA3.15
unnamed: DS3.6, LA3.16
unnamed: DS3.7, LA3.17
unnamed: DS3.9, LA3.19
unnamed: DS3.10, LA3.18
unnamed: DS4.1, LA4.12
unnamed: DS4.2, LA4.13
unnamed: DS4.4, LA4.14
unnamed: DS4.5, LA4.15
unnamed: DS4.6, LA4.16
unnamed: DS4.7, LA4.17
unnamed: DS4.9, LA4.19
unnamed: DS4.10, LA4.18
unnamed: DS5.1, LA5.12
unnamed: DS5.2, LA5.13
unnamed: DS5.4, LA5.14
unnamed: DS5.5, LA5.15
unnamed: DS5.6, LA5.16
unnamed: DS5.7, LA5.17
unnamed: DS5.9, LA5.19
unnamed: DS5.10, LA5.18
unnamed: DS6.1, LA6.12
unnamed: DS6.2, LA6.13
unnamed: DS6.4, LA6.14
unnamed: DS6.5, LA6.15
unnamed: DS6.6, LA6.16
unnamed: DS6.7, LA6.17
unnamed: DS6.9, LA6.19
unnamed: DS6.10, LA6.18
unnamed: DS7.1, LA7.12
unnamed: DS7.2, LA7.13
unnamed: DS7.4, LA7.14
unnamed: DS7.5, LA7.15
unnamed: DS7.6, LA7.16
unnamed: DS7.7, LA7.17
unnamed: DS7.9, LA7.19
unnamed: DS7.10, LA7.18
unnamed: DS8.1, LA8.12
unnamed: DS8.2, LA8.13
unnamed: DS8.4, LA8.14
unnamed: DS8.5, LA8.15
unnamed: DS8.6, LA8.16
unnamed: DS8.7, LA8.17
unnamed: DS8.9, LA8.19
unnamed: DS8.10, LA8.18
unnamed: DS9.1, LA9.12
unnamed: DS9.2, LA9.13
unnamed: DS9.4, LA9.14
unnamed: DS9.5, LA9.15
unnamed: DS9.6, LA9.16
unnamed: DS9.7, LA9.17
unnamed: DS9.9, LA9.19
unnamed: DS9.10, LA9.18
unnamed: DS10.1, LA10.12
unnamed: DS10.2, LA10.13
unnamed: DS10.4, LA10.14
unnamed: DS10.5, LA10.15
unnamed: DS10.6, LA10.16
unnamed: DS10.7, LA10.17
unnamed: DS10.9, LA10.19
unnamed: DS10.10, LA10.18
unnamed: DS11.1, LA11.12
unnamed: DS11.2, LA11.13
unnamed: DS11.4, LA11.14
unnamed: DS11.5, LA11.15
unnamed: DS11.6, LA11.16
unnamed: DS11.7, LA11.17
unnamed: DS11.9, LA11.19
unnamed: DS11.10, LA11.18
unnamed: DS12.1, LA12.12
unnamed: DS12.2, LA12.13
unnamed: DS12.4, LA12.14
unnamed: DS12.5, LA12.15
unnamed: DS12.6, LA12.16
unnamed: DS12.7, LA12.17
unnamed: DS12.9, LA12.19
unnamed: DS12.10, LA12.18
unnamed: DS13.1, LA13.12
unnamed: DS13.2, LA13.13
unnamed: DS13.4, LA13.14
unnamed: DS13.5, LA13.15
unnamed: DS13.6, LA13.16
unnamed: DS13.7, LA13.17
unnamed: DS13.9, LA13.19
unnamed: DS13.10, LA13.18
unnamed: DS14.1, LA14.12
unnamed: DS14.2, LA14.13
unnamed: DS14.4, LA14.14
unnamed: DS14.5, LA14.15
unnamed: DS14.6, LA14.16
unnamed: DS14.7, LA14.17
unnamed: DS14.9, LA14.19
unnamed: DS14.10, LA14.18
unnamed: DS15.1, LA15.12
unnamed: DS15.2, LA15.13
unnamed: DS15.4, LA15.14
unnamed: DS15.5, LA15.15
unnamed: DS15.6, LA15.16
unnamed: DS15.7, LA15.17
unnamed: DS15.9, LA15.19
unnamed: DS15.10, LA15.18
unnamed: DS16.1, LA16.12
unnamed: DS16.2, LA16.13
unnamed: DS16.4, LA16.14
unnamed: DS16.5, LA16.15
unnamed: DS16.6, LA16.16
unnamed: DS16.7, LA16.17
unnamed: DS16.9, LA16.19
unnamed: DS16.10, LA16.18
unnamed: DS17.1, LA17.12
unnamed: DS17.2, LA17.13
unnamed: DS17.4, LA17.14
unnamed: DS17.5, LA17.15
unnamed: DS17.6, LA17.16
unnamed: DS17.7, LA17.17
unnamed: DS17.9, LA17.19
unnamed: DS17.10, LA17.18
unnamed: DS18.1, LA18.12
unnamed: DS18.2, LA18.13
unnamed: DS18.4, LA18.14
unnamed: DS18.5, LA18.15
unnamed: DS18.6, LA18.16
unnamed: DS18.7, LA18.17
unnamed: DS18.9, LA18.19
unnamed: DS18.10, LA18.18
unnamed: DS19.1, LA19.12
unnamed: DS19.2, LA19.13
unnamed: DS19.4, LA19.14
unnamed: DS19.5, LA19.15
unnamed: DS19.6, LA19.16
unnamed: DS19.7, LA19.17
unnamed: DS19.9, LA19.19
unnamed: DS19.10, LA19.18
unnamed: DS20.1, LA20.12
unnamed: DS20.2, LA20.13
unnamed: DS20.4, LA20.14
unnamed: DS20.5, LA20.15
unnamed: DS20.6, LA20.16
unnamed: DS20.7, LA20.17
unnamed: DS20.9, LA20.19
unnamed: DS20.10, LA20.18
unnamed: DS21.1, LA21.12
unnamed: DS21.2, LA21.13
unnamed: DS21.4, LA21.14
unnamed: DS21.5, LA21.15
unnamed: DS21.6, LA21.16
unnamed: DS21.7, LA21.17
unnamed: DS21.9, LA21.19
unnamed: DS21.10, LA21.18
unnamed: DS22.1, LA22.12
unnamed: DS22.2, LA22.13
unnamed: DS22.4, LA22.14
unnamed: DS22.5, LA22.15
unnamed: DS22.6, LA22.16
unnamed: DS22.7, LA22.17
unnamed: DS22.9, LA22.19
unnamed: DS22.10, LA22.18
unnamed: DS23.1, LA23.12
unnamed: DS23.2, LA23.13
unnamed: DS23.4, LA23.14
unnamed: DS23.5, LA23.15
unnamed: DS23.6, LA23.16
unnamed: DS23.7, LA23.17
unnamed: DS23.9, LA23.19
unnamed: DS23.10, LA23.18
unnamed: DS24.1, LA24.12
unnamed: DS24.2, LA24.13
unnamed: DS24.4, LA24.14
unnamed: DS24.5, LA24.15
unnamed: DS24.6, LA24.16
unnamed: DS24.7, LA24.17
unnamed: DS24.9, LA24.19
unnamed: DS24.10, LA24.18
unnamed: DS25.1, LA25.12
unnamed: DS25.2, LA25.13
unnamed: DS25.4, LA25.14
unnamed: DS25.5, LA25.15
unnamed: DS25.6, LA25.16
unnamed: DS25.7, LA25.17
unnamed: DS25.9, LA25.19
unnamed: DS25.10, LA25.18
unnamed: DS26.1, LA26.12
unnamed: DS26.2, LA26.13
unnamed: DS26.4, LA26.14
unnamed: DS26.5, LA26.15
unnamed: DS26.6, LA26.16
unnamed: DS26.7, LA26.17
unnamed: DS26.9, LA26.19
unnamed: DS26.10, LA26.18
unnamed: DS27.1, LA27.12
unnamed: DS27.2, LA27.13
unnamed: DS27.4, LA27.14
unnamed: DS27.5, LA27.15
unnamed: DS27.6, LA27.16
unnamed: DS27.7, LA27.17
unnamed: DS27.9, LA27.19
unnamed: DS27.10, LA27.18
unnamed: DS28.1, LA28.12
unnamed: DS28.2, LA28.13
unnamed: DS28.4, LA28.14
unnamed: DS28.5, LA28.15
unnamed: DS28.6, LA28.16
unnamed: DS28.7, LA28.17
unnamed: DS28.9, LA28.19
unnamed: DS28.10, LA28.18
unnamed: DS29.1, LA29.12
unnamed: DS29.2, LA29.13
unnamed: DS29.4, LA29.14
unnamed: DS29.5, LA29.15
unnamed: DS29.6, LA29.16
unnamed: DS29.7, LA29.17
unnamed: DS29.9, LA29.19
unnamed: DS29.10, LA29.18
unnamed: DS30.1, LA30.12
unnamed: DS30.2, LA30.13
unnamed: DS30.4, LA30.14
unnamed: DS30.5, LA30.15
unnamed: DS30.6, LA30.16
unnamed: DS30.7, LA30.17
unnamed: DS30.9, LA30.19
unnamed: DS30.10, LA30.18
unnamed: DS31.1, LA31.12
unnamed: DS31.2, LA31.13
unnamed: DS31.4, LA31.14
unnamed: DS31.5, LA31.15
unnamed: DS31.6, LA31.16
unnamed: DS31.7, LA31.17
unnamed: DS31.9, LA31.19
unnamed: DS31.10, LA31.18
unnamed: DS32.1, LA32.12
unnamed: DS32.2, LA32.13
unnamed: DS32.4, LA32.14
unnamed: DS32.5, LA32.15
unnamed: DS32.6, LA32.16
unnamed: DS32.7, LA32.17
unnamed: DS32.9, LA32.19
unnamed: DS32.10, LA32.18
unnamed: DS33.1, LA33.12
unnamed: DS33.2, LA33.13
unnamed: DS33.4, LA33.14
unnamed: DS33.5, LA33.15
unnamed: DS33.6, LA33.16
unnamed: DS33.7, LA33.17
unnamed: DS33.9, LA33.19
unnamed: DS33.10, LA33.18
unnamed: DS34.1, LA34.12
unnamed: DS34.2, LA34.13
unnamed: DS34.4, LA34.14
unnamed: DS34.5, LA34.15
unnamed: DS34.6, LA34.16
unnamed: DS34.7, LA34.17
unnamed: DS34.9, LA34.19
unnamed: DS34.10, LA34.18
unnamed: DS35.1, LA35.12
unnamed: DS35.2, LA35.13
unnamed: DS35.4, LA35.14
unnamed: DS35.5, LA35.15
unnamed: DS35.6, LA35.16
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

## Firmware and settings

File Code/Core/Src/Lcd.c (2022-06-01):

#include "Lcd.h"
#include "main.h"
#include <stm32g441xx.h>
#include <stm32g4xx_hal.h>
#include <stdarg.h>
#include <stdio.h>


uint8_t displayMode = 0b1000;

uint32_t DWT_Delay_Init(void)
{
	CoreDebug->DEMCR &= ~CoreDebug_DEMCR_TRCENA_Msk;
	CoreDebug->DEMCR |= CoreDebug_DEMCR_TRCENA_Msk;

	DWT->CTRL &= ~DWT_CTRL_CYCCNTENA_Msk;
	DWT->CTRL |= DWT_CTRL_CYCCNTENA_Msk;

	DWT->CYCCNT = 0;

	__ASM volatile ("NOP");
	__ASM volatile ("NOP");
	__ASM volatile ("NOP");

	if(DWT->CYCCNT)
	{
		return 0;
	}
	else
	{
		return 1;
	}

}

void DWT_Delay_us(volatile uint32_t micros)
{
	uint32_t iniTicks = DWT->CYCCNT;
	uint32_t ticks = 100000000 / 1000000;
	micros *= ticks;
	while((DWT->CYCCNT - iniTicks) < micros - ticks);
}

void DWT_Delay_ms(volatile uint32_t millis)
{
	uint32_t iniTicks = DWT->CYCCNT;
	uint32_t ticks = 100000000 / 1000;
	millis *= ticks;
	while((DWT->CYCCNT - iniTicks) < millis);
}

void setE(uint8_t sOrC)
{
	uint32_t ePortOut;
	ePortOut = E_PORT->ODR;

	if (sOrC)
	{
		ePortOut |= (1<<E_PIN);
	}
	else
	{
		ePortOut &= ~(1<<E_PIN);
	}

	E_PORT->ODR = ePortOut;
}

void setRW(uint8_t sOrC)
{
	uint16_t rWPortOut;
	rWPortOut = RW_PORT->ODR;

	if (sOrC)
	{
		rWPortOut |= (1<<RW_PIN);
	}
	else
	{
		rWPortOut &= ~(1<<RW_PIN);
	}

	RW_PORT->ODR = rWPortOut;
}

void setRS(uint8_t sOrC)
{
	uint16_t rSPortOut;
	rSPortOut = RS_PORT->ODR;

	if (sOrC)
	{
		rSPortOut |= (1<<RS_PIN);
	}
	else
	{
		rSPortOut &= ~(1<<RS_PIN);
	}

	RS_PORT->ODR = rSPortOut;
}


#ifndef FOUR_BIT_OPERATION

void sendByte(uint8_t byte)
{
	uint16_t portOut;
	portOut = DATA_PORT->ODR;

	portOut &= ~(1 << DB4) & ~(1<<DB5) & ~(1<<DB6) & ~(1<<DB7) & 
		~(1 << DB0) & ~(1<<DB1) & ~(1<<DB2) & ~(1<<DB3); 

	portOut |= (byte >> 0 & 0b1) << DB0;
	portOut |= (byte >> 1 & 0b1) << DB1;
	portOut |= (byte >> 2 & 0b1) << DB2;
	portOut |= (byte >> 3 & 0b1) << DB3;
	portOut |= (byte >> 4 & 0b1) << DB4;
	portOut |= (byte >> 5 & 0b1) << DB5;
	portOut |= (byte >> 6 & 0b1) << DB6;
	portOut |= (byte >> 7 & 0b1) << DB7;

	DATA_PORT->ODR = portOut;

	setE(0);
	setE(1);
	setE(0);
}

#else

void sendNibble(uint8_t nibble)
{
	uint16_t portOut;
	portOut = DATA_PORT->ODR;

	nibble = ((nibble << 4 ) >> 4);

	portOut &= ~(1 << DB4) & ~(1<<DB5) & ~(1<<DB6) & ~(1<<DB7);

	portOut |= (nibble & 0b1) << DB4;
	portOut |= (nibble >> 1 & 0b1) << DB5;
	portOut |= (nibble >> 2 & 0b1) << DB6;
	portOut |= (nibble >> 3 & 0b1) << DB7;

	DATA_PORT->ODR = portOut;

}

void sendByte(uint8_t data)
{

	sendNibble(data >> 4);

	setE(0);
	setE(1);
	setE(0);

	DWT_Delay_us(300);

	sendNibble(data);

	setE(0);
	setE(1);
	setE(0);

	DWT_Delay_us(300);

}

#endif

int isBusy()
{
	DATA_PORT->MODER &= ~(0b11 << ((DB7 << 1)));

	setRW(1);
	setRS(0);
	setE(1);

	int isBusy = 0;

	if (DATA_PORT->IDR & (1<<DB7))
		isBusy = 1;

	setE(0);
	DATA_PORT->MODER |= (0b01 << ((DB7 << 1)));
	
	return isBusy;
}

void waitWhileBusy()
{
	DATA_PORT->MODER &= ~(0b11 << ((DB7 << 1)));

	setRW(1);
	setRS(0);
	setE(1);
	while(DATA_PORT->IDR & (1<<DB7))
	{
		setE(0);
		setE(1);
		setE(0);
		setE(1);
	}

	setE(0);
	DATA_PORT->MODER |= (0b01 << ((DB7 << 1)));
}

void sendInstruction(uint8_t data)
{
	// Make sure the display isn't busy
	waitWhileBusy();
	
	setRW(0);
	setRS(0);

	sendByte(data);

}


void writeDisplay(uint8_t data)
{
	// Make sure the display isn't busy
	waitWhileBusy();

	setRW(0);
	setRS(1);

	sendByte(data);

}

#ifndef FOUR_BIT_OPERATION

void initDisplay(void)
{
	// Enable the GPIO for the data port
	RCC->AHB1ENR |= (1<<RCC_DATA_ENR);

	// Set each of the data lines to outputs
	DATA_PORT->MODER &= ~(0b11 << (DB4 << 1)) & ~(0b11 << (DB5 << 1)) & ~(0b11 << (DB6 << 1)) & ~(0b11 << (DB7 << 1));
					 &  ~(0b11 << (DB0 << 1)) & ~(0b11 << (DB1 << 1)) & ~(0b11 << (DB2 << 1)) & ~(0b11 << (DB3 << 1));
	DATA_PORT->MODER |= (0b01 << (DB4 << 1)) | (0b01 << (DB5 << 1)) | (0b01 << (DB6 << 1)) | (0b01 << (DB7 << 1))
					 |  (0b01 << (DB0 << 1)) | (0b01 << (DB1 << 1)) | (0b01 << (DB2 << 1)) | (0b01 << (DB3 << 1));
	
	// Enable the GPIO for the RW port
	RCC->AHB1ENR |= (1<<RCC_RW_ENR);

	// Set the rw line to output
	RW_PORT->MODER &= ~(0b11 << (RW_PIN << 1));
	RW_PORT->MODER |= (0b01 << (RW_PIN << 1));

	// Enable the GPIO for the RS port
	RCC->AHB1ENR |= (1<<RCC_RS_ENR);

	// Set the rs line to output
	RS_PORT->MODER &= ~(0b11 << (RS_PIN << 1));
	RS_PORT->MODER |= (0b01 << (RS_PIN << 1));

	// Enable the GPIO for the E port
	RCC->AHB1ENR |= (1<<RCC_E_ENR);

	// Set the e line to output
	E_PORT->MODER &= ~(0b11 << (E_PIN << 1));
	E_PORT->MODER |= (0b01 << (E_PIN << 1));


	// When initializing they recommend 15 ms delay until after vcc rises above 4.5V
	DWT_Delay_ms(15);

	// Set RS and RW for Writing (RW) Instructions (RS)
	setRW(0);
	setRS(0);

	// Function set see datasheet
	sendByte(0b00110000);

	// Datasheet recommends 4.1ms delay here
	DWT_Delay_us(4100);

	// Function set see datasheet
	sendByte(0b00110000);

	// Datasheet recommends 100us delay here
	DWT_Delay_us(100);

	// Function set see datasheet
	sendByte(0b00110000);

	// Function set, 4 bit mode, 2 lines, 8x5 dots
	sendInstruction(0b00111000);
	
	// Display off
	sendInstruction(0b00001000);

	// Display clear
	sendInstruction(0b00000001);

	// Entry set
	sendInstruction(0b00000110);

}

#else
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

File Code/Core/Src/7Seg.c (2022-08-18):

#include "7Seg.h"
#include "stm32g4xx_hal.h"
#include <stm32g441xx.h>

const int oneDraw[4][4] =
{
	{NONE, D_SHAPE , ALL_SEVEN, NONE	},
	{NONE, NONE	   , ALL_SEVEN, NONE	},
	{NONE, NONE	   , ALL_SEVEN, NONE	},
	{NONE, BOTTOM_O, ALL_SEVEN, BOTTOM_O}
};

const int twoDraw[4][4] =
{
    {NONE, D_SHAPE, TOP_O, B_SHAPE},
    {NONE, NONE, NONE, ALL_SEVEN},
    {NONE, D_SHAPE, P_SHAPE, T_L_CORNER},
    {NONE, ALL_SEVEN, BOTTOM_O, BOTTOM_O}
	// {BOTTOM_O, TOP_O   , TOP_O	 , BOTTOM_O},
	// {NONE	 , NONE	   , D_SHAPE , P_SHAPE },
	// {NONE	 , D_SHAPE , P_SHAPE , NONE	   },
	// {Q_SHAPE , BOTTOM_O, BOTTOM_O, P_SHAPE }
};

const int threeDraw[4][4] =
{
	{NONE, TOP_O		, TOP_O	  , B_SHAPE},
	{NONE	, B_R_CORNER, BOTTOM_O, P_SHAPE},
	{NONE	, T_R_CORNER, TOP_O	  , B_SHAPE},
	{NONE, BOTTOM_O	, BOTTOM_O, P_SHAPE}
};

const int fourDraw[4][4] =
{
	{NONE	, ALL_SEVEN	  , NONE	, ALL_SEVEN},
	{NONE	, ALL_SEVEN , NONE	, ALL_SEVEN},
	{NONE, TOP_O, TOP_O, ALL_SEVEN},
	{NONE	, NONE	  , NONE	, ALL_SEVEN}
};

const int fiveDraw[4][4] =
{
	{NONE,	ALL_SEVEN	, TOP_O	  , TOP_O	  },
	{NONE,	ALL_SEVEN, BOTTOM_O, B_L_CORNER},
	{NONE ,	BOTTOM_O	, NONE	  , ALL_SEVEN },
	{NONE  ,	Q_SHAPE, BOTTOM_O, P_SHAPE   }
};

const int sixDraw[4][4] =
{
	{NONE  ,	D_SHAPE	, Q_SHAPE , B_SHAPE	  },
	{NONE,	ALL_SEVEN, BOTTOM_O, B_L_CORNER},
	{NONE,	ALL_SEVEN	, NONE	  , ALL_SEVEN },
	{NONE  ,	Q_SHAPE, BOTTOM_O, P_SHAPE	  }
};

const int sevenDraw[4][4] =
{
	{NONE, TOP_O	 , TOP_O  , ALL_SEVEN},
	{NONE ,	NONE	 , D_SHAPE, NONE	 },
	{NONE ,	ALL_SEVEN, NONE   , NONE	 },
	{NONE ,	ALL_SEVEN, NONE   , NONE	 }
};

const int eightDraw[4][4] =
{
	{NONE , D_SHAPE   , TOP_O   , B_SHAPE },
	{NONE 	 , Q_SHAPE, BOTTOM_O, P_SHAPE   },
	{NONE, D_SHAPE   , TOP_O   , B_SHAPE},
	{NONE , Q_SHAPE, BOTTOM_O, P_SHAPE }
};

const int nineDraw[4][4] =
{
	{NONE   , D_SHAPE  , TOP_O  , B_SHAPE  },
	{NONE , ALL_SEVEN	, NONE   , ALL_SEVEN},
	{NONE, T_R_CORNER  , TOP_O  , ALL_SEVEN},
	{NONE   , BOTTOM_O, D_SHAPE, P_SHAPE  }
};

const int zeroDraw[4][4] =
{
	{D_SHAPE   , TOP_O  , TOP_O  , B_SHAPE  },
	{ALL_SEVEN , NONE	, NONE   , ALL_SEVEN},
	{ALL_SEVEN , NONE   , NONE   , ALL_SEVEN},
	{Q_SHAPE   , B_SHAPE, D_SHAPE, P_SHAPE  }
};

const int (* numDraws[10])[4][4] = {&zeroDraw, &oneDraw, &twoDraw, &threeDraw, &fourDraw, &fiveDraw, &sixDraw, &sevenDraw, &eightDraw, &nineDraw};

const int displayAddresses[4][17] = {
    // 0     1    2      3      4    5     6     7     8     9    10     11    12    13   14     15    16
    {0x30, 0x28, 0x08, 0x10, 0x31, 0x29, 0x09, 0x11, 0x34, 0x32, 0x2a, 0x0a, 0x12, 0x33, 0x2b, 0x0b, 0x13}, // 0
    {0x38, 0x20, 0x18, 0x00, 0x39, 0x21, 0x19, 0x01, 0x3c, 0x3a, 0x22, 0x1a, 0x02, 0x3b, 0x23, 0x1b, 0x03}, // 1
    {0x58, 0x50, 0x68, 0x60, 0x59, 0x51, 0x69, 0x61, 0x5c, 0x5a, 0x52, 0x6a, 0x62, 0x5b, 0x53, 0x6b, 0x63}, // 2
    {0x40, 0x48, 0x70, 0x78, 0x41, 0x49, 0x71, 0x79, 0x44, 0x42, 0x4a, 0x72, 0x7a, 0x43, 0x4b, 0x73, 0x7b}  // 3
};

const int secretOrder[2][68] = 
{
    {3, 7,12,16, 2, 6,11,15, 3, 7,12,16, 2, 6,11,15, 1, 5,10,14, 1, 5,10,14, 0, 4, 9,13, 8, 0, 4, 9,13, 8, 0, 4, 9,13, 8, 1, 5,10,14, 1, 5,10,14, 0, 4, 9,13, 8, 3, 7,12,16, 2, 6,11,15, 2, 6,11,15, 3, 7,12,16},
    {1, 1, 1, 1, 0, 0, 0, 0, 0, 0, 0, 0, 1, 1, 1, 1, 1, 1, 1, 1, 0, 0, 0, 0, 0, 0, 0, 0, 0, 1, 1, 1, 1, 1, 3, 3, 3, 3, 3, 3, 3, 3, 3, 2, 2, 2, 2, 2, 2, 2, 2, 2, 2, 2, 2, 2, 2, 2, 2, 2, 3, 3, 3, 3, 3, 3, 3, 3}
};

int lastDisplayState[4][17] = { 
    {-1, -1, -1, -1, -1, -1, -1, -1, -1, -1, -1, -1, -1, -1, -1, -1, -1},
    {-1, -1, -1, -1, -1, -1, -1, -1, -1, -1, -1, -1, -1, -1, -1, -1, -1},
    {-1, -1, -1, -1, -1, -1, -1, -1, -1, -1, -1, -1, -1, -1, -1, -1, -1},
    {-1, -1, -1, -1, -1, -1, -1, -1, -1, -1, -1, -1, -1, -1, -1, -1, -1},
 };

int displayState[4][17] = { 0 };

void updateDisplayCell(int data, int row, int col)
{
    displayState[row][col] = data;
}

void updateDisplayWithTime(int hr, int min)
{
    for (int i = 0; i < 4; i++)
    {
        for (int j = 0; j < 4; j++)
        {
            int data = (*numDraws[hr / 10])[j][i];
            updateDisplayCell(data, j, i);
        }
    }
    for (int i = 4; i < 8; i++)
    {
        for (int j = 0; j < 4; j++)
        {
            int data = (*numDraws[hr % 10])[j][i - 4];
            updateDisplayCell(data, j, i);
        }
    }
    
    updateDisplayCell(0x00, 0, 8);
    updateDisplayCell(DEC_POINT, 1, 8);
    updateDisplayCell(DEC_POINT, 2, 8);
    updateDisplayCell(0x00, 3, 8);

    for (int i = 9; i < 13; i++)
    {
        for (int j = 0; j < 4; j++)
        {
            int data = (*numDraws[min / 10])[j][i - 9];
            updateDisplayCell(data, j, i);
        }
    }
    for (int i = 13; i < 17; i++)
    {
        for (int j = 0; j < 4; j++)
        {
            int data = (*numDraws[min % 10])[j][i - 13];
            updateDisplayCell(data, j, i);
        }
    }
}

/* This is what will change with different computing units*/
void setDisplayCell(int row, int col)
{
    int pOut = (displayState[row][col] << 0) | ((displayAddresses[row][col] << 9));
    //uint16_t pA = pOut & (0b0000000000000000);
	uint16_t pB = pOut & (0b1111111011111111);
	//GPIOA->ODR = pA;
    GPIOB->ODR = pB;

    HAL_Delay(1);

    pOut |= (0b0000111000000000);
    //pA = pOut & (0b1110011111101111);
	pB = pOut & (0b1111111011111111);
	//GPIOA->ODR = pA;
	GPIOB->ODR = pB;

    HAL_Delay(1);
}

void setDisplayForce()
{
    for (int i = 0; i < 68; i++)
    {
        //for (int j = 0; j < 4; j++)
        //{
            int r = secretOrder[1][i];
            int c = secretOrder[0][i];
            setDisplayCell(r, c);
            lastDisplayState[r][c] = displayState[r][c];

        //}
    }
    return;
}

void setDisplay()
{
    for (int i = 0; i < 68; i++)
    {
        //for (int j = 0; j < 4; j++)
        //{
            int r = secretOrder[1][i];
            int c = secretOrder[0][i];
            if (displayState[r][c] != lastDisplayState[r][c])
            {
                setDisplayCell(r, c);
                lastDisplayState[r][c] = displayState[r][c];
            }
        //}
    }

    // WORKAROUND THAT IS STUPID AND IM SORRY BUT IM TIRED AND IT WORKS CONSISTENTLY
    setDisplayCell(2, 15);
    // END WORKAROUND
    return;
}

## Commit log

2022-08-18 Calibration added
2022-08-19 Calibration updated
2022-10-15 Added circuit board files
    [LatchTest-B_Cu.gbr, LatchTest-B_Mask.gbr, LatchTest-B_Paste.gbr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]
2022-10-15 Added some photos of pcb and schematic
    [LatchTest-B_Cu.gbr, LatchTest-B_Mask.gbr, LatchTest-B_Paste.gbr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]

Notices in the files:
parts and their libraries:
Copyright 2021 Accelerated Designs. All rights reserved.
